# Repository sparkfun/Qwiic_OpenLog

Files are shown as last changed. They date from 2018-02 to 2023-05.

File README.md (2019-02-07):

SparkFun Qwiic OpenLog
========================================

SparkFun Qwiic OpenLog

[*SparkFun Qwiic OpenLog (DEV-15164)*](https://www.sparkfun.com/products/15164)

The [Qwiic](https://www.sparkfun.com/qwiic) system makes it easy to read all sorts of sensors, but what if you want to log that data? Qwiic OpenLog is an easy to use I2C based data logger. Simply write code like:

    recordToOpenLog("The battery voltage is:");
    recordToOpenLog(batteryVoltage);

And your data will be recorded to LOG00001.TXT for later review. 

The SparkFun Qwiic OpenLog is the smarter and better looking cousin to the extremely popular [OpenLog](https://www.sparkfun.com/products/13712). We've ported the serial based interface to I2C. Now you can daisy chain lots of I2C devices and log them all without taking up your serial port.

We've written a large number of example sketches to show how to record logs, create new logs, create and navigate directories, remove files and directories, and read the contents of files. 

Qwiic OpenLog supports clock stretching which means it performs even better than the original! Qwiic OpenLog will record data up to 21,000 bytes per second at 400kHz. As the receive buffer fills up QOL will hold the clock line letting the master know that it is busy. Once QOL is finished with a task it releases the clock allowing the data to continue flowing without corruption.

Need to get freaky and have multiple data loggers on the same bus? You're in luck. Qwiic OpenLog has both a solder jumper to allow for two devices on the same bus as well as a software setting to allow for the setting of any I2C address. Don't get too freaky though; the limit is 111 devices (0x08 to 0x77) on the same bus. Any microSD card will work so with 64GB cards you'll be limited to approximately 7 Terabytes of storage :(

We will be adding more features to the firmware over time and we've made it very easy to upgrade! If you're comfortable sending a sketch to an Uno then you can upgrade the firmware on Qwiic OpenLog.

Repository Contents
-------------------

* **/Firmware/Qwiic_OpenLog** - The core sketch that runs Qwiic OpenLog
* **/Hardware** - Eagle design files (.brd, .sch)

Documentation
--------------
* **[Library](https://github.com/sparkfun/SparkFun_Qwiic_OpenLog_Arduino_Library)** - Arduino library for the Qwiic OpenLog.
* **[Hookup Guide](https://learn.sparkfun.com/tutorials/qwiic-openlog-hookup-guide)** - Basic hookup guide for the Qwiic OpenLog.
* **[SparkFun Fritzing repo](https://github.com/sparkfun/Fritzing_Parts)** - Fritzing diagrams for SparkFun products.

License Information
-------------------

This product is _**open source**_! 

Please review the LICENSE.md file for license information. 

If you have any questions or concerns on licensing, please contact techsupport@sparkfun.com.

Please use, reuse, and modify these files as you see fit. Please maintain attribution to SparkFun Electronics and release any derivative under the same license.

Distributed as-is; no warranty is given.

- Your friends at SparkFun.

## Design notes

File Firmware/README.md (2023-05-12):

Library Dependencies:

* [SerialPort](https://github.com/greiman/SerialPort)
    * Users will need to manually install the [`SerialPort` folder](https://github.com/greiman/SerialPort/tree/master/SerialPort) from this repository as an Arduino library
        * Method 1:
            * Download or clone the repository
            * Compress the [`SerialPort` folder](https://github.com/greiman/SerialPort/tree/master/SerialPort) into a `*.zip` file
            * In the Arduino IDE, install the library from the drop-down menu: **Sketch** > **Include Library** > **Add .ZIP Library**
        * Method 2:
            * Download or clone the repository
            * Copy the [`SerialPort` folder](https://github.com/greiman/SerialPort/tree/master/SerialPort) into the directory for the Arduino libraries
* [SdFat *(v1.1.4)*](https://github.com/greiman/SdFat)
    * To avoid compile issues, please use v1.1.4 (or another version prior to v2.x.x) of the SDFat Arduino library

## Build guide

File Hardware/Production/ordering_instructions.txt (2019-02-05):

panel size, 195x122mm
PCB thickness, 1.6mm
number of layers, 2
soldermask color, Red
silkscreen color, White
oz copper, 1oz
finish, HASL lead free
stencils, top+bottom
pcs per panel, 28

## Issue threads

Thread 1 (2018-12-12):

Add Pullup on CS

nseidle, 2018-12-12:
Add ~10k pull up on SD CS so that the device can be programmed in test jig with SD card inserted. Otherwise the CS pin is left floating and can cause errors when the SD card tries to take over MISO during programming and testing.

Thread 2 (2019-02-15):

Example sketch won't compile, "default argument given for parameter 2"

mantonakakis1, 2019-02-15:
Example 1 sketch won't compile, I get the following error message(s):

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

If I remove the default argument from the sendCommand definition in the .cpp file, it compiles, i.e. when:
`boolean OpenLog::sendCommand(uint8_t registerNumber, String option1)`
replaces:
`boolean OpenLog::sendCommand(uint8_t registerNumber, String option1 = "")`

Using a SparkFun SAMD21 Pro RF and the SparkX qwiic OpenLog, I have another issue once the code is uploaded - the output of my .txt file on the SD card, running Example 1, looks like:
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

This matches an issue I had with another version of the library (as of Jan 26th, 2019) when used with the same hardware - randomly missing characters in the output file, skipped new lines, although no random up arrows (raised as an issue in the github for that version of the library, [here](https://github.com/sparkfun/SparkFun_Qwiic_OpenLog_Arduino_Library/issues/3)). Running the same sketch multiple times resulted in completely random point of error, i.e. sometimes a new line would come out correctly, other times it wouldn't, and would cut off in random spots. Now, with this version, I get the random up-arrows, as well as the randomly cut off lines.

Last I checked, the circa 1/26/2019 version of the library worked fine when the SparkX qwiic OpenLog was hooked up to a BlackBoard instead of the SAMD21 Pro RF.

AndyEngland521, 2019-02-15:
The SparkX version of the OpenLog runs a different firmware version than the new SparkFun OpenLog. You will need to update the firmware on your SparkX OpenLog to the most current version (contained in this repo) in order to get things working. In the mean time I'm looking into your compile error on SAMD21.

mattljc, 2019-02-24:
I'm having similar issues with the Red version of the qwiic OpenLog connected to a SAMD21 RedBoard Turbo. Running example 1 results in missing characters and missing newlines.

Things tried so far:
- Adding 100ms delays after print statements to ensure the buffers clear
- Increasing and decreasing the I2C clock speed
- Reducing string lengths to 8 chars

mantonakakis1, 2019-03-10:
> The SparkX version of the OpenLog runs a different firmware version than the new SparkFun OpenLog. You will need to update the firmware on your SparkX OpenLog to the most current version (contained in this repo) in order to get things working. In the mean time I'm looking into your compile error on SAMD21.

Updated the SparkX Qwiic OpenLog to firmware 2.0 by uploading the Qwiic_OpenLog.ino file from the latest firmware folder using an FTDI board (confirmed the firmware update worked by changing the "no card" error from 3 blinks to 2 blinks), making sure I followed the instructions in the HookUp guide regarding supprting libraries.

I then tried writing some simple data to the SD card with a BlackBoard. It writes consistently, but it is SLOW. With 20ms delay between three print commands (time, a comma, and a counter value), I get about 1.5 to 1.8 seconds per loop. It was also extremely slow running some of the examples in the library.

Tomorrow I will test with the non-X version of the OpenLog, without any firmware changes from the way it shipped, using the BlackBoard.

Here's the code I tested with:
```
#include <Wire.h>
#include "SparkFun_Qwiic_OpenLog_Arduino_Library.h"
OpenLog myLog;

int now = 0;
int loopDelay = 20;
int count = 0;

void setup()
{
  Serial.begin(9600);
  Serial.println("Starting");
  Wire.begin();
  Wire.setClock(400000);
  pinMode(LED_BUILTIN, OUTPUT);
  delay(100);
  myLog.begin();
  delay(100);
}

void loop()
{
  now = millis();
  myLog.print(now);
  delay(loopDelay);
  myLog.print(", ");
  delay(loopDelay);
  myLog.println(count);
  count++;
  digitalWrite(LED_BUILTIN, HIGH);
  delay(20);
  digitalWrite(LED_BUILTIN, LOW);
}
```

mantonakakis1, 2019-03-11:
After my last post I reflashed the firmware without any changes, and it suddenly worked a bit better - but for the 60ms of total delay in my loop function, I was getting about 150-250ms per loop. After a few seconds, one of the times through the loop would slow down a lot, closer to 1s, then back to ~200ms.

Tried the same sketch with the new "red" version of the Qwiic OpenLog with whatever firmware it shipped with, and got the same result.

Tried another SparkX version of the board, with whatever firmware it shipped with about 2 months ago, and it wrote much faster, subjectively looked like it was running at the full 60ms loop speed. Unfortunately, the new library doesn't match the firmware it and prints the garbled output with the "spades" symbols (so I can't say for sure how fast it was).

So I think I can conclude the following with a bit of confidence:
- New firmware is quite slow, regardless of board version, using the latest firmware and libraries on a BlackBoard.
- Old firmware doesn't work well with new libraries, which makes sense.
- New version of the board with stock firmware writes faster with a SAMD21 board, but incomplete print commands, missed new lines, etc.

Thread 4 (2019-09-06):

Can't flash OpenLog Qwiic

Stefal, 2019-09-06:
Hi!

My goal is to use OpenLog Qwiic as a standalone logger for the SparkFun GPS-RTK2 Board - ZED-F9P (Qwiic).

I've quick tested the OpenLog with an Arduino Uno and the OpenLog arduino library, and it's working.
My first step is simply updating the firmware with the latest one available here.
Then I will customize the code to log the F9P (any help is welcome).

But, I can't flash the OpenLog.

I've soldered the ftdi pins
Connected the OpenLog with an Adafruit Ftdi Friend/Sparkfun FTDI Basic 3.3v to a Windows Computer/Ubuntu Computer, and I always have the same problem :
```
avrdude: stk500_recv(): programmer is not responding
avrdude: stk500_getsync() attempt 1 of 10: not in sync: resp=0xde
```

I don't understand where is the problem.

nseidle, 2019-09-06:
Just to be sure - did you get the Qwiic OpenLog from us? It's happened a few times where derivatives from other mfgs neglect/forget the bootloader.

The board should have a regular Uno/Optiboot bootloader preloaded onto the board. Be sure nothing else is connected to the board except your FTDI. Sounds like your already at 3.3V on the FTDI (good). Try loading the basic blink sketch onto OpenLog. The Stat pin is pin 13 so the default BLINK sketch should work.

Stefal, 2019-09-06:
I bought it from [Digikey](https://www.digikey.fr/product-detail/en/sparkfun-electronics/DEV-15164/1568-DEV-15164-ND/9920435)

I can't flash the Blink sketch, I receive the same "not responding" error.

BTW : In all cases, when I start to upload the sketch, I see some activity on the FTDI adapter.

Thank you for your answer

Closed 2019-11-27.

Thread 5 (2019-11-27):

OpenLog Qwiic not working with STM32F429 Nucleo 144 Board

patilakash, 2019-11-27:
I am trying to log the data from STM32F429 board to Qwiic logger through I2C port. Below is settings for I2C in STM32F429
Address Mode: 10Bit
Clock Speed: 400K

Following commands are sent from STM32F429 board
1. Sent Data as "Testing"
2. Sent Register Address "13"
3. Sent Register Address "10"
4. Sent Register Address "17"

The I2C device ID used to communicate with Qwiic log is 42.

Please help me to solve the above issue. I have tested the Qwiic board with Arduino UNO and it is working.

AndyEngland521, 2019-11-27:
@patilakash hmmm, looks like the problem might be that you're using 10 bit addressing. If I remember correctly, the OpenLog and other Qwiic devices use an 8-bit addressing scheme. Check out the following [article](https://www.totalphase.com/support/articles/200349176-7-bit-8-bit-and-10-bit-I2C-Slave-Addressing)

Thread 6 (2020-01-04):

Characters dropped on Teensy 4.0

robertstuart, 2020-01-04:
When I compile and run the code below for a Teensy 4.0, many characters are dropped.  A typical output is also shown below.  The errors seem to be random. Adding delay(20) lines in the code seems to have no effect.  When I run the same code on an Arduino Mini Pro, the output is perfect.  I really, really would like to get this fixed.  Any ideas?

Just as a side note, I should mention that there is a compile error when compiling for a Teensy 3.2.  I don't need this but I thought someone should know.
```

#include <Wire.h>
#include "SparkFun_Qwiic_OpenLog_Arduino_Library.h"
OpenLog myLog; //Create instance

int ledPin = 13; //Status LED connected to digital pin 13
char message[100] = "";

void setup() {
  Serial.begin(115200);
  pinMode(ledPin, OUTPUT);
  Wire.begin(); //Initialize I2C
  myLog.begin(); //Open connection to OpenLog (no pun intended)
  for (float i = 0.0; i < 9.1; i += 0.5) {
    Serial.print(i); Serial.print(",");
    myLog.print(i); myLog.print(",");
    Serial.print(sqrt(i)); Serial.print(",");
    myLog.print(sqrt(i)); myLog.print(",");
    Serial.print(i / 0.99); Serial.print(",");
    myLog.print(i / 0.99); myLog.print(",");
    Serial.print(i * 1.1), Serial.print(",");
    myLog.print(i * 1.1), myLog.print(",");
    Serial.println(i);
    myLog.println(i);
  }
  myLog.syncFile();
}

void loop() {
  digitalWrite(ledPin, HIGH);
  delay(100);
  digitalWrite(ledPin, LOW);
  delay(1000);
}

```
```
0.00,0.00,0.00,0.00,0.00
0.50,0.710.51,0.55,0.50
1.00,1.00,1.01,1.10,1.00
1.50,1.22,1.52,1.65,1.50
2.00,1.41,2.02,2.20,2.00
2.50,1.58,2.53,2.75,2.50
3.00,1.73,3.03,3.30,3.00
3.50,1.87,3.5,3.85,3.50
4.00,2.00,4.04,4.40,4.00
4.50,2.12,4.55,4.95,4.50
5.00,2.24,5.05,5.50,5.00
5.0,2.35,5.56,6.05,5.50
6.00,2.45,6.06,6.60,6.00
6.50,2.55,6.57,7.15,6.50
7.00,2.65,7.07,7.0,7.00
7.50,2.74,7.58,8.25,7.50
8.00,2.83,8.08,8.80,8.00
8.50,2.92,8.59,9.35,8.50
9.00,3.00,9.09,9.90,9.0

```

Gambit120, 2021-03-31:
I am having the same issue on the teensy 4.0. I read some ware that there need to be a short delay between each character not between each write. I thought the library would have done this for you but it looks like you need to do it in your code.

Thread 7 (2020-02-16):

Errors in code

prem-prakash, 2020-02-16:
https://github.com/sparkfun/Qwiic_OpenLog/blob/4ad46f22de5928e600c73eadc97cb77bcad5d950/Firmware/Qwiic_OpenLog/Qwiic_OpenLog.ino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

this line should not be

```c++
  case ERROR_VOLUME_INIT:
      NewSerial.print(F("volume.init"));
      blink_error(ERROR_VOLUME_INIT);
      break;
```

otherwise, all errors blink the same number of times, a little bit confusing

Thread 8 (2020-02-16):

Compilation errors

prem-prakash, 2020-02-16:
Compile firmware code returning errors

```
Processing Qwiic_OpenLog (src_filter: +<Qwiic_OpenLog.cpp>; platform: atmelavr; framework: arduino; board: ATmega328; targets: program; monitor_speed: 115200; lib_deps: SdFat=https://github.com/greiman/SdFat-beta.git#7016042d22ec9e4a3fe93565bfff1d61fb8271e2)
-----------------------------------------------------------------------------------------------------------------------------------------------------------------------
CONFIGURATION: https://docs.platformio.org/page/boards/atmelavr/ATmega328.html
PLATFORM: Atmel AVR 2.0.0 > ATmega328
HARDWARE: ATMEGA328 16MHz, 2KB RAM, 31.50KB Flash
PACKAGES: toolchain-atmelavr 1.50400.190710 (5.4.0), framework-arduino-avr-minicore 2.0.3, tool-avrdude 1.60300.190628 (6.3.0)
LDF: Library Dependency Finder -> http://bit.ly/configure-pio-ldf
LDF Modes: Finder ~ chain, Compatibility ~ soft
Found 9 compatible libraries
Scanning dependencies...
Dependency Graph
|-- <SdFat> #7016042 [git+https://github.com/greiman/SdFat-beta.git#7016042d22ec9e4a3fe93565bfff1d61fb8271e2] (/Users/prakash/Projects/embedded/Qwiic_OpenLog/.pio/libdeps/Qwiic_OpenLog/SdFat)
|   |-- <SPI> 1.0 (/Users/prakash/.platformio/packages/framework-arduino-avr-minicore/libraries/SPI)
|-- <EEPROM> 2.0 (/Users/prakash/.platformio/packages/framework-arduino-avr-minicore/libraries/EEPROM)
|-- <SPI> 1.0 (/Users/prakash/.platformio/packages/framework-arduino-avr-minicore/libraries/SPI)
|-- <Wire> 1.0 (/Users/prakash/.platformio/packages/framework-arduino-avr-minicore/libraries/Wire)
Building in release mode
avr-g++ -o .pio/build/Qwiic_OpenLog/src/Qwiic_OpenLog.cpp.o -c -fno-exceptions -fno-threadsafe-statics -fpermissive -std=gnu++11 -Os -Wall -ffunction-sections -fdata-sections -flto -mmcu=atmega328 -DPLATFORMIO=40100 -DARDUINO_AVR_ATmega328 -DF_CPU=16000000L -DARDUINO_ARCH_AVR -DARDUINO=10808 -Iinclude -Isrc -I/Users/prakash/.platformio/packages/framework-arduino-avr-minicore/libraries/Wire/src -I/Users/prakash/.platformio/packages/framework-arduino-avr-minicore/libraries/EEPROM/src -I.pio/libdeps/Qwiic_OpenLog/SdFat -I/Users/prakash/.platformio/packages/framework-arduino-avr-minicore/libraries/SPI/src -I/Users/prakash/.platformio/packages/framework-arduino-avr-minicore/cores/MiniCore -I/Users/prakash/.platformio/packages/framework-arduino-avr-minicore/variants/standard src/Qwiic_OpenLog.cpp
In file included from .pio/libdeps/Qwiic_OpenLog/SdFat/SdFat/src/FatLib/FatLib.h:28:0,
                 from .pio/libdeps/Qwiic_OpenLog/SdFat/SdFat/src/SdFat.h:27,
                 from src/Qwiic_OpenLog.cpp:93:
.pio/libdeps/Qwiic_OpenLog/SdFat/SdFat/src/FatLib/StdioStream.h:289:24: warning: 'prog_char' is deprecated [-Wdeprecated-declarations]
   int fputs_P(PGM_P str);
                        ^
In file included from src/Qwiic_OpenLog.cpp:94:0:
include/SerialPort.h:243:41: warning: 'prog_char' is deprecated [-Wdeprecated-declarations]
   buf_size_t put_P(PGM_P b, buf_size_t n);
                                         ^
include/SerialPort.h:547:35: warning: 'prog_char' is deprecated [-Wdeprecated-declarations]
   size_t write_P(PGM_P b, size_t n) {
                                   ^
include/SerialPort.h: In member function 'size_t SerialPort<PortNumber, RxBufSize, TxBufSize>::write(const __FlashStringHelper*)':
include/SerialPort.h:583:22: warning: 'prog_char' is deprecated: prog_char type is deprecated. [-Wdeprecated-declarations]
     const prog_char* p = (const prog_char*)s;
                      ^
In file included from /Users/prakash/.platformio/packages/framework-arduino-avr-minicore/cores/MiniCore/Arduino.h:28:0,
                 from /Users/prakash/.platformio/packages/framework-arduino-avr-minicore/libraries/Wire/src/Wire.h:25,
                 from src/Qwiic_OpenLog.cpp:91:
/Users/prakash/.platformio/packages/toolchain-atmelavr/avr/include/avr/pgmspace.h:354:14: note: declared here
 typedef char prog_char __attribute__((__progmem__,deprecated("prog_char type is deprecated.")));
              ^
In file included from src/Qwiic_OpenLog.cpp:94:0:
include/SerialPort.h:583:42: warning: 'prog_char' is deprecated: prog_char type is deprecated. [-Wdeprecated-declarations]
     const prog_char* p = (const prog_char*)s;
                                          ^
In file included from /Users/prakash/.platformio/packages/framework-arduino-avr-minicore/cores/MiniCore/Arduino.h:28:0,
                 from /Users/prakash/.platformio/packages/framework-arduino-avr-minicore/libraries/Wire/src/Wire.h:25,
                 from src/Qwiic_OpenLog.cpp:91:
/Users/prakash/.platformio/packages/toolchain-atmelavr/avr/include/avr/pgmspace.h:354:14: note: declared here
 typedef char prog_char __attribute__((__progmem__,deprecated("prog_char type is deprecated.")));
              ^
src/Qwiic_OpenLog.cpp: In function 'void recordConfigFile()':
src/Qwiic_OpenLog.cpp:603:62: warning: comparison between signed and unsigned integer expressions [-Wsign-compare]
   if (myFile.write(settings_string, strlen(settings_string)) != strlen(settings_string))
                                                              ^
src/Qwiic_OpenLog.cpp: In function 'void loadArrayWithFileName(FatFile*, char*)':
src/Qwiic_OpenLog.cpp:1183:53: warning: invalid conversion from 'byte* {aka unsigned char*}' to 'char*' [-fpermissive]
   responseSize = sprintf(responseBuffer, "%s", fname) + 1; //Add 1 for null terminator
                                                     ^
In file included from /Users/prakash/.platformio/packages/framework-arduino-avr-minicore/cores/MiniCore/Print.h:24:0,
                 from /Users/prakash/.platformio/packages/framework-arduino-avr-minicore/cores/MiniCore/Stream.h:26,
                 from /Users/prakash/.platformio/packages/framework-arduino-avr-minicore/cores/MiniCore/HardwareSerial.h:29,
                 from /Users/prakash/.platformio/packages/framework-arduino-avr-minicore/cores/MiniCore/Arduino.h:288,
                 from /Users/prakash/.platformio/packages/framework-arduino-avr-minicore/libraries/Wire/src/Wire.h:25,
                 from src/Qwiic_OpenLog.cpp:91:
/Users/prakash/.platformio/packages/toolchain-atmelavr/avr/include/stdio.h:671:12: note:   initializing argument 1 of 'int sprintf(char*, const char*, ...)'
 extern int sprintf(char *__s, const char *__fmt, ...);
            ^
src/Qwiic_OpenLog.cpp: In function 'void listFiles(char*)':
src/Qwiic_OpenLog.cpp:1206:12: warning: ISO C++ forbids converting a string constant to 'char*' [-Wwrite-strings]
     myData = "*\0";       // use global wildcard=
            ^
src/Qwiic_OpenLog.cpp: In function 'void receiveEvent(int)':
src/Qwiic_OpenLog.cpp:1363:31: warning: comparison between signed and unsigned integer expressions [-Wsign-compare]
   for (int regNum = 0; regNum < (sizeof(memoryMap) / sizeof(byte)); regNum++)
                               ^
src/Qwiic_OpenLog.cpp:1369:52: warning: invalid conversion from 'byte* {aka unsigned char*}' to 'char*' [-fpermissive]
       functions[regNum].handleFunction(incomingData);
                                                    ^
In file included from src/Qwiic_OpenLog.cpp:96:0:
src/Qwiic_OpenLog.cpp: At top level:
.pio/libdeps/Qwiic_OpenLog/SdFat/SdFat/src/FreeStack.h:40:12: warning: 'FreeStack' defined but not used [-Wunused-function]
 static int FreeStack() {
            ^
avr-g++ -o .pio/build/Qwiic_OpenLog/firmware.elf -Os -mmcu=atmega328 -Wl,--gc-sections -flto -fuse-linker-plugin .pio/build/Qwiic_OpenLog/src/Qwiic_OpenLog.cpp.o -L.pio/build/Qwiic_OpenLog -Wl,--start-group .pio/build/Qwiic_OpenLog/lib10a/libSPI.a .pio/build/Qwiic_OpenLog/lib201/libSdFat.a .pio/build/Qwiic_OpenLog/lib356/libEEPROM.a .pio/build/Qwiic_OpenLog/libff3/libWire.a .pio/build/Qwiic_OpenLog/libFrameworkArduinoVariant.a .pio/build/Qwiic_OpenLog/libFrameworkArduino.a -lm -Wl,--end-group
/var/folders/f2/ps6dm9rs3y7dqg7xr8_k9_2h0000gn/T//ccy0Fwvq.ltrans0.ltrans.o: In function `SerialPort<(unsigned char)0, 32u, 32u>::flush()':
<artificial>:(.text+0x6c6): undefined reference to `txRingBuf'
<artificial>:(.text+0x6ca): undefined reference to `txRingBuf'
<artificial>:(.text+0x6ce): undefined reference to `txRingBuf'
<artificial>:(.text+0x6d2): undefined reference to `txRingBuf'
/var/folders/f2/ps6dm9rs3y7dqg7xr8_k9_2h0000gn/T//ccy0Fwvq.ltrans0.ltrans.o: In function `SerialPort<(unsigned char)0, 32u, 32u>::peek()':
<artificial>:(.text+0xe1c): undefined reference to `rxRingBuf'
<artificial>:(.text+0xe1e): undefined reference to `rxRingBuf'
<artificial>:(.text+0xe20): undefined reference to `SerialRingBuffer::peek()'
/var/folders/f2/ps6dm9rs3y7dqg7xr8_k9_2h0000gn/T//ccy0Fwvq.ltrans0.ltrans.o: In function `SerialPort<(unsigned char)0, 32u, 32u>::read()':
<artificial>:(.text+0xe34): undefined reference to `rxRingBuf'
<artificial>:(.text+0xe36): undefined reference to `rxRingBuf'
<artificial>:(.text+0xe38): undefined reference to `SerialRingBuffer::get(unsigned char*)'
/var/folders/f2/ps6dm9rs3y7dqg7xr8_k9_2h0000gn/T//ccy0Fwvq.ltrans0.ltrans.o: In function `SerialPort<(unsigned char)0, 32u, 32u>::available()':
<artificial>:(.text+0xe52): undefined reference to `rxRingBuf'
<artificial>:(.text+0xe54): undefined reference to `rxRingBuf'
<artificial>:(.text+0xe56): undefined reference to `SerialRingBuffer::available()'
/var/folders/f2/ps6dm9rs3y7dqg7xr8_k9_2h0000gn/T//ccy0Fwvq.ltrans0.ltrans.o: In function `SerialPort<(unsigned char)0, 32u, 32u>::write(unsigned char const*, unsigned int)':
<artificial>:(.text+0xe76): undefined reference to `txRingBuf'
<artificial>:(.text+0xe78): undefined reference to `txRingBuf'
<artificial>:(.text+0xe7a): undefined reference to `SerialRingBuffer::put(unsigned char const*, unsigned int)'
/var/folders/f2/ps6dm9rs3y7dqg7xr8_k9_2h0000gn/T//ccy0Fwvq.ltrans0.ltrans.o: In function `SerialPort<(unsigned char)0, 32u, 32u>::write(unsigned char)':
<artificial>:(.text+0xeaa): undefined reference to `txRingBuf'
<artificial>:(.text+0xeac): undefined reference to `txRingBuf'
<artificial>:(.text+0xeae): undefined reference to `SerialRingBuffer::put(unsigned char)'
/var/folders/f2/ps6dm9rs3y7dqg7xr8_k9_2h0000gn/T//ccy0Fwvq.ltrans0.ltrans.o: In function `global constructors keyed to 65535_0_Qwiic_OpenLog.cpp.o.3638':
<artificial>:(.text.startup+0x40): undefined reference to `rxRingBuf'
<artificial>:(.text.startup+0x42): undefined reference to `rxRingBuf'
<artificial>:(.text.startup+0x44): undefined reference to `SerialRingBuffer::init(unsigned char*, unsigned int)'
<artificial>:(.text.startup+0x50): undefined reference to `txRingBuf'
<artificial>:(.text.startup+0x52): undefined reference to `txRingBuf'
<artificial>:(.text.startup+0x54): undefined reference to `SerialRingBuffer::init(unsigned char*, unsigned int)'
/var/folders/f2/ps6dm9rs3y7dqg7xr8_k9_2h0000gn/T//ccy0Fwvq.ltrans0.ltrans.o: In function `main':
<artificial>:(.text.startup+0xea): undefined reference to `fopen'
<artificial>:(.text.startup+0x170): undefined reference to `fopen'
collect2: error: ld returned 1 exit status
```

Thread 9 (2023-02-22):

Problem on interfacing Qwiic OpenLog throught NUCLEO STM32 L432KC

DamianTadzik, 2023-02-22:
I'm trying to write my own library for my own use, based on Arduino library and information that SparkFun provided about this logger but i'm always recievieng HAL_error. I do not know where to find help or information about configuring this device, and it feels like register map is useless because any of those addresses doesn't respond.

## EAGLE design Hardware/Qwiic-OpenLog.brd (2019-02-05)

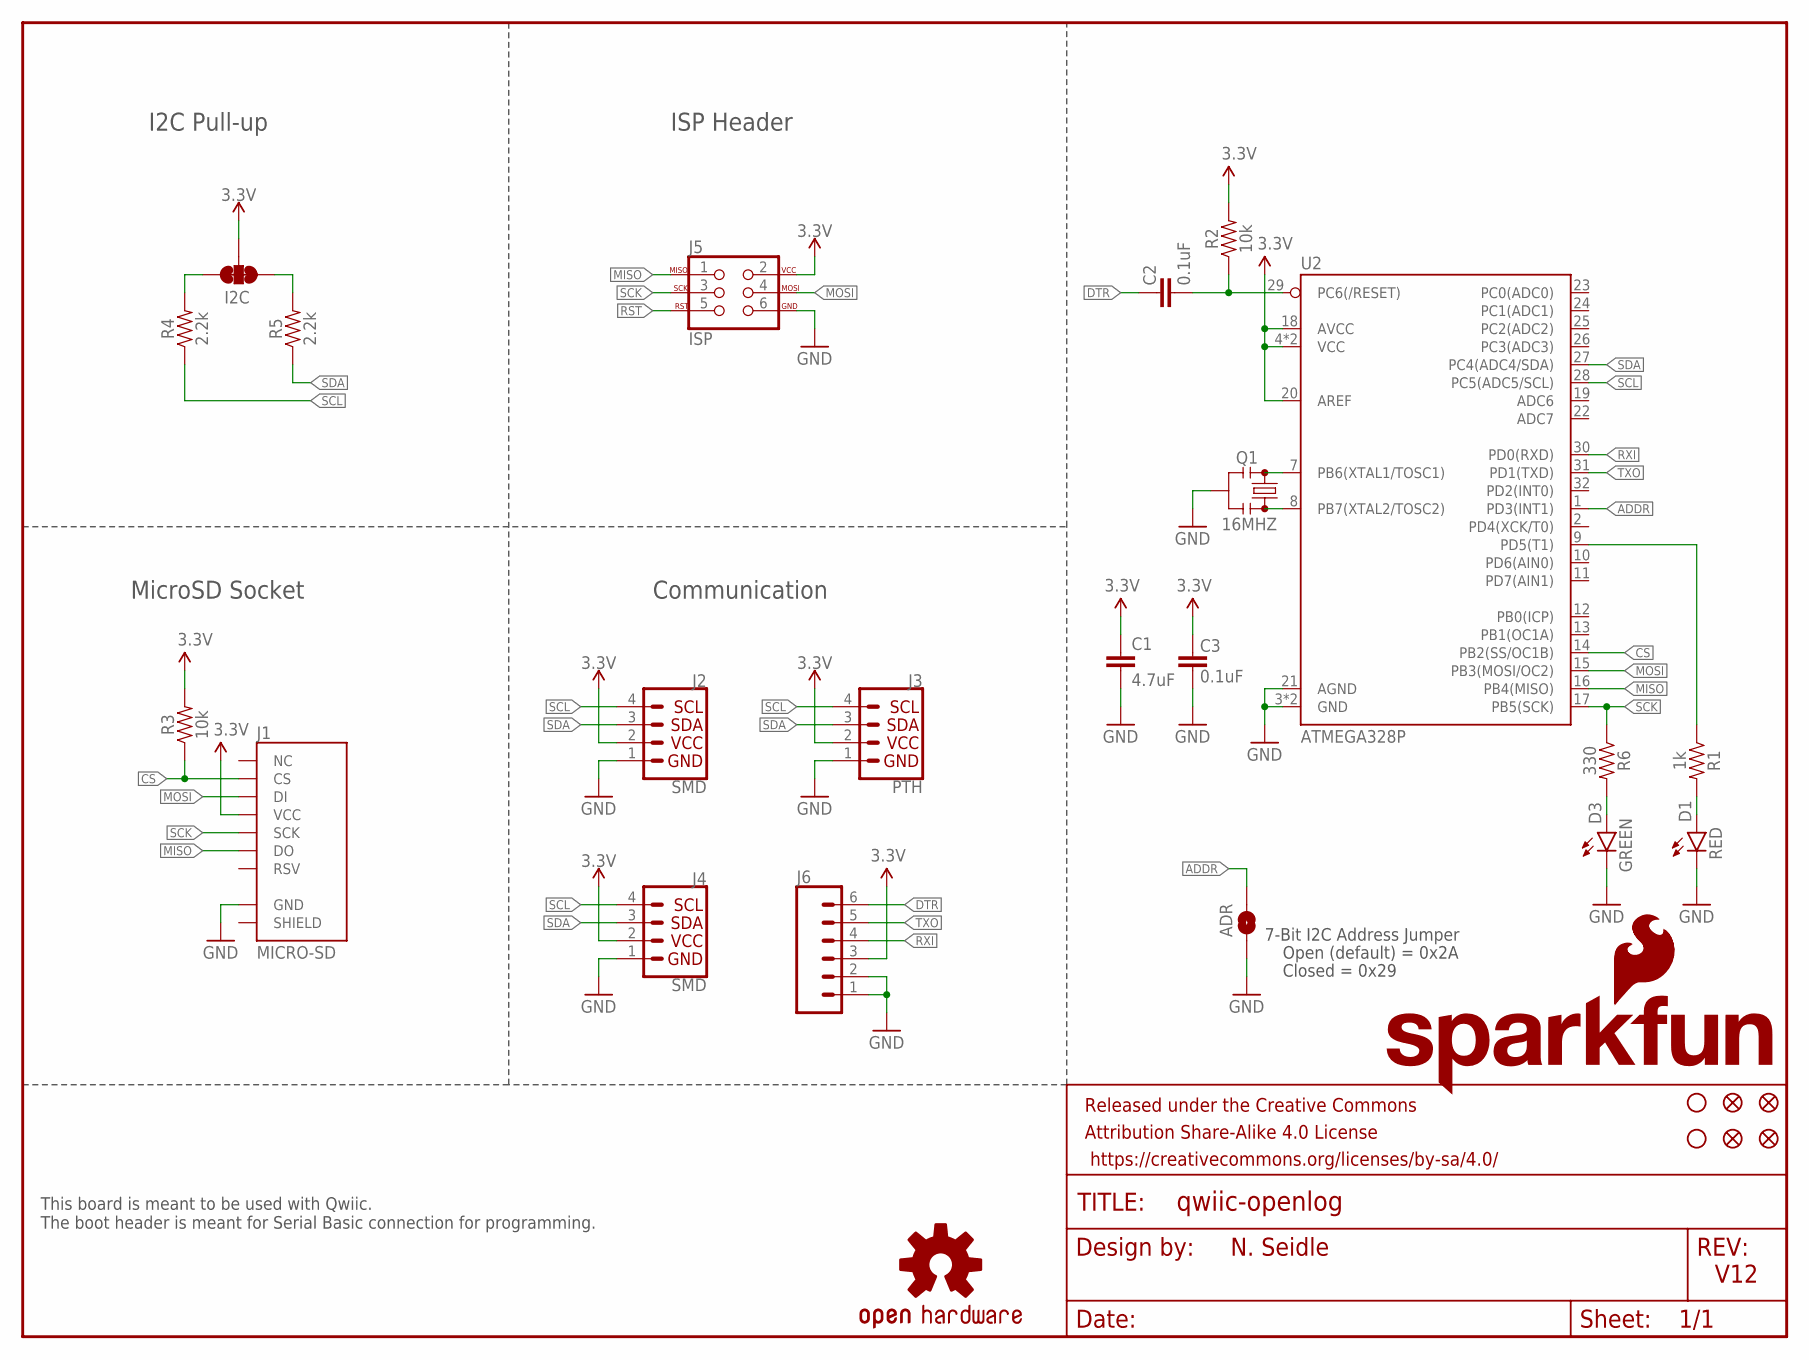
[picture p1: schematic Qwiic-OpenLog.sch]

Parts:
ADR: SOLDERJUMPERNO; SJ_2S-NO
C1: 4.7uF; 0603
C2, C3: 0.1uF; 0603
D1: RED; LED-0603
D3: GREEN; LED-0603
FID1, FID2, FID3, FID4: FIDUCIALUFIDUCIAL; FIDUCIAL-MICRO
FRAME1: FRAME-LETTER; CREATIVE_COMMONS
I2C: JUMPER-SMT_3_2-NC_TRACE_SILK; SMT-JUMPER_3_2-NC_TRACE_SILK
J1: MICRO-SD; MICRO-SD-SOCKET
J2, J4: SMD; 1X04_1MM_RA
J3: PTH; 1X04_NO_SILK
J5: ISP; 2X3_TEST_POINTS
J6: CONN_06NO_SILK_NO_POP; 1X06_NO_SILK
JP3, JP4: STAND-OFF
LOGO1: SFE_LOGO_FLAME.1_INCH; SFE_LOGO_FLAME_.1
LOGO2: OSHW-LOGOMINI; OSHW-LOGO-MINI
LOGO4: SFE_LOGO_NAME_FLAME.1_INCH; SFE_LOGO_NAME_FLAME_.1
Q1: 16MHZ; RESONATOR-SMD
R1: 1k; 0603
R2, R3: 10k; 0603
R4, R5: 2.2k; 0603
R6: 330; 0603
U2: ATMEGA328P; TQFP32-08

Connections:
3.3V: C1.1, C3.2, I2C.2, J1.VCC, J2.2, J3.2 (VCC), J4.2, J5.2, J6.3, R2.2, R3.2, U2.4 (VCC), U2.6 (VCC), U2.18 (AVCC), U2.20 (AREF)
ADDR: ADR.2, U2.1 (PD3(INT1))
CS: J1.CS, R3.1, U2.14 (PB2(SS/OC1B))
DTR: C2.2, J6.6
GND: ADR.1, C1.2, C3.1, D1.C, D3.C, J1.GND, J2.1, J3.1 (GND), J4.1, J5.6, J6.1, J6.2, Q1.2, U2.3 (GND), U2.5 (GND), U2.21 (AGND)
MISO: J1.DO, J5.1, U2.16 (PB4(MISO))
MOSI: J1.DI, J5.4, U2.15 (PB3(MOSI/OC2))
unnamed: Q1.1, U2.8 (PB7(XTAL2/TOSC2))
unnamed: Q1.3, U2.7 (PB6(XTAL1/TOSC1))
unnamed: D1.A, R1.2
unnamed: R1.1, U2.9 (PD5(T1))
unnamed: I2C.1, R5.2
unnamed: I2C.3, R4.2
unnamed: D3.A, R6.2
RST: C2.1, J5.5, R2.1, U2.29 (PC6(/RESET))
RXI: J6.4, U2.30 (PD0(RXD))
SCK: J1.SCLK (SCK), J5.3, R6.1, U2.17 (PB5(SCK))
SCL: J2.4, J3.4 (SCL), J4.4, R4.1, U2.28 (PC5(ADC5/SCL))
SDA: J2.3, J3.3 (SDA), J4.3, R5.1, U2.27 (PC4(ADC4/SDA))
TXO: J6.5, U2.31 (PD1(TXD))

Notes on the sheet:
This board is meant to be used with Qwiic. The boot header is meant for Serial Basic connection for programming.
V12
N. Seidle
I2C Pull-up
Communication
MicroSD Socket
ISP Header
7-Bit I2C Address Jumper
Closed = 0x29
Open (default) = 0x2A

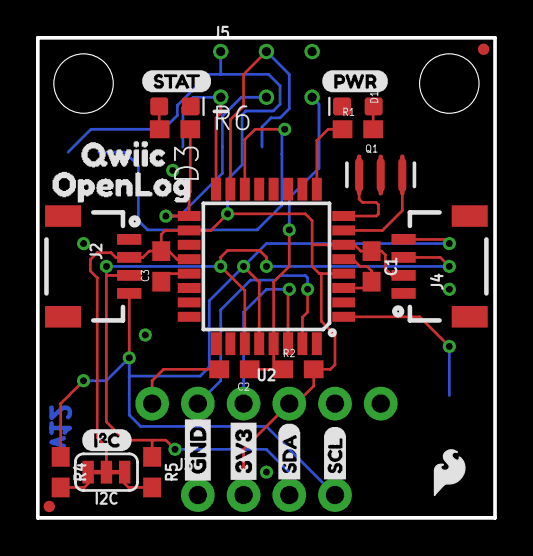
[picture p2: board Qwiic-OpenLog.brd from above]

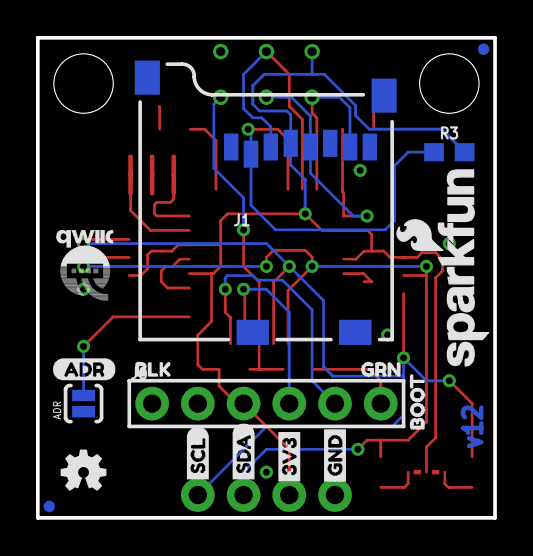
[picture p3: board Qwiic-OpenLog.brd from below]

Board: 2 copper layers, 25.4 x 26.7 mm, 49 parts (17 on the bottom side), 20 nets.

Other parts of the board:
U$3: QWIIC-LOGO-SMALL
U$4: 3V3-03
U$5: GND-03
U$6: 3V30
U$7: ADR-()-03
U$8: I_SUPER2_C-()-03
U$9: PWR-()-03
U$10: BLK3
U$11: BOOT5
U$12: GRN4
U$13, U$16: SDA1
U$14: QWIIC7
U$15, U$19: SCL2
U$17: STAT0
U$18: OPENLOG0
U$20: GND1

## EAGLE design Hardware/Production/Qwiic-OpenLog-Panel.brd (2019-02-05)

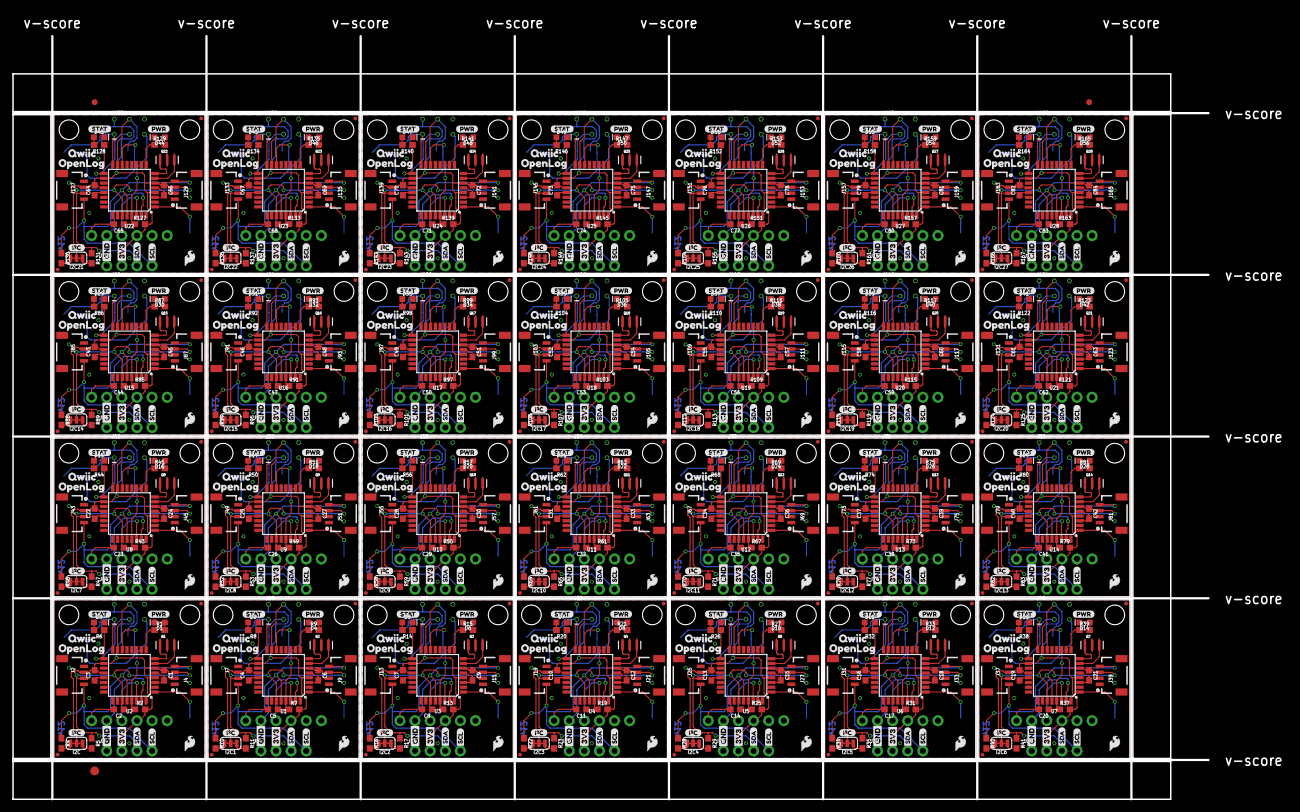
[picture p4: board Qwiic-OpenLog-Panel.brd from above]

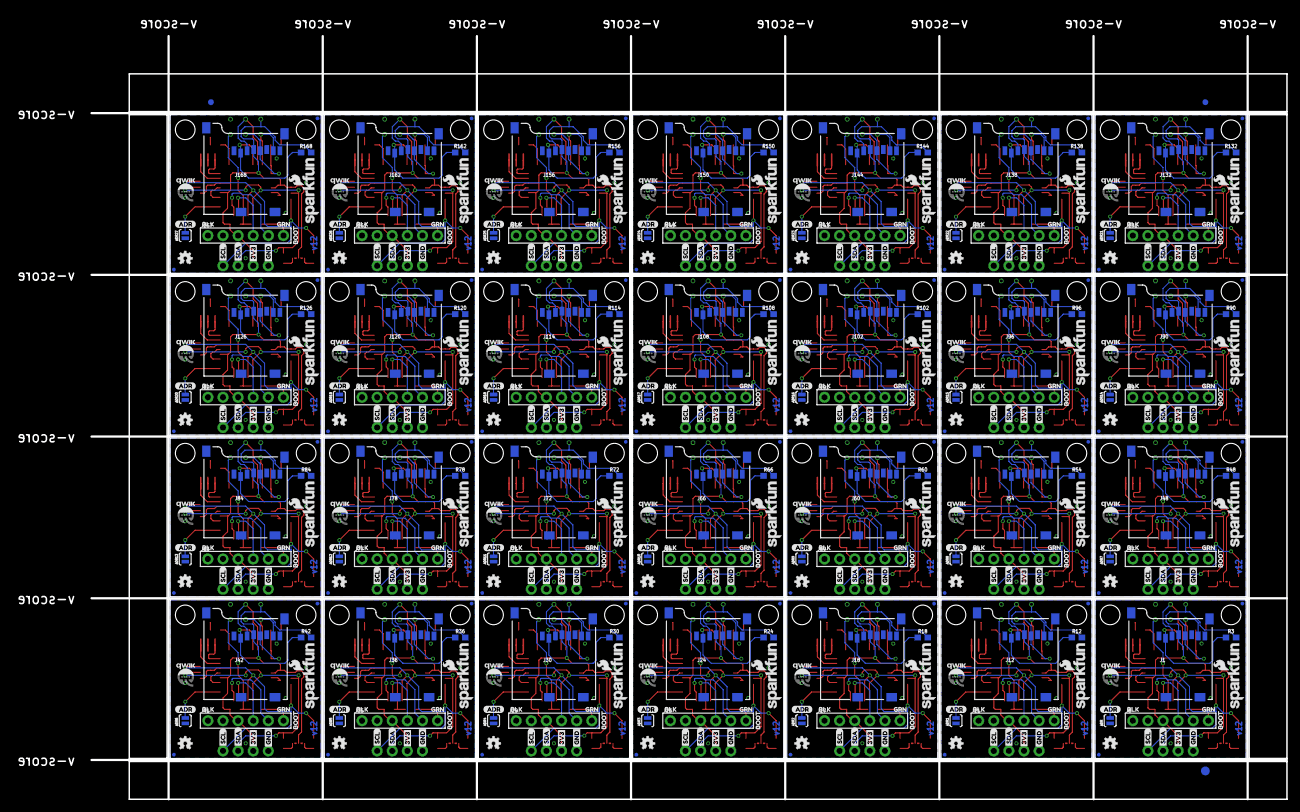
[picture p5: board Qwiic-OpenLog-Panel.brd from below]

Board: 2 copper layers, 200.9 x 128.3 mm, 1350 parts (479 on the bottom side), 560 nets.

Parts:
ADR, ADR1, ADR2, ADR3, ADR4, ADR5, ADR6, ADR7, ADR8, ADR9, ADR10, ADR11, ADR12, ADR13, ADR14, ADR15, ADR16, ADR17, ADR18, ADR19, ADR20, ADR21, ADR22, ADR23, ADR24, ADR25, ADR26, ADR27: SJ_2S-NO
C1, C6, C9, C12, C15, C18, C21, C24, C27, C30, C33, C36, C39, C42, C45, C48, C51, C54, C57, C60, C63, C66, C69, C72, C75, C78, C81, C84: 4.7uF; 0603
C2, C3, C4, C5, C7, C8, C10, C11, C13, C14, C16, C17, C19, C20, C22, C23, C25, C26, C28, C29, C31, C32, C34, C35, C37, C38, C40, C41, C43, C44, C46, C47, C49, C50, C52, C53, C55, C56, C58, C59, C61, C62, C64, C65, C67, C68, C70, C71, C73, C74, C76, C77, C79, C80, C82, C83: 0.1uF; 0603
D1, D4, D6, D8, D10, D12, D14, D16, D18, D20, D22, D24, D26, D28, D30, D32, D34, D36, D38, D40, D42, D44, D46, D48, D50, D52, D54, D56: RED; LED-0603
D2, D3, D5, D7, D9, D11, D13, D15, D17, D19, D21, D23, D25, D27, D29, D31, D33, D35, D37, D39, D41, D43, D45, D47, D49, D51, D53, D55: GREEN; LED-0603
E$1, E$2, E$3, E$4: FIDUCIAL-1X2
E$5, E$6: FIDUCIAL-1.5X3
FID1, FID2, FID3, FID4, FID5, FID6, FID7, FID8, FID9, FID10, FID11, FID12, FID13, FID14, FID15, FID16, FID17, FID18, FID19, FID20, FID21, FID22, FID23, FID24, FID25, FID26, FID27, FID28, FID29, FID30, FID31, FID32, FID33, FID34, FID35, FID36, FID37, FID38, FID39, FID40, FID41, FID42, FID43, FID44, FID45, FID46, FID47, FID48, FID49, FID50, FID51, FID52, FID53, FID54, FID55, FID56, FID57, FID58, FID59, FID60, FID61, FID62, FID63, FID64, FID65, FID66, FID67, FID68, FID69, FID70, FID71, FID72, FID73, FID74, FID75, FID76, FID77, FID78, FID79, FID80, FID81, FID82, FID83, FID84, FID85, FID86, FID87, FID88, FID89, FID90, FID91, FID92, FID93, FID94, FID95, FID96, FID97, FID98, FID99, FID100, FID101, FID102, FID103, FID104, FID105, FID106, FID107, FID108, FID109, FID110, FID111, FID112: FIDUCIALUFIDUCIAL; FIDUCIAL-MICRO
I2C, I2C1, I2C2, I2C3, I2C4, I2C5, I2C6, I2C7, I2C8, I2C9, I2C10, I2C11, I2C12, I2C13, I2C14, I2C15, I2C16, I2C17, I2C18, I2C19, I2C20, I2C21, I2C22, I2C23, I2C24, I2C25, I2C26, I2C27: SMT-JUMPER_3_2-NC_TRACE_SILK
J1, J12, J18, J24, J30, J36, J42, J48, J54, J60, J66, J72, J78, J84, J90, J96, J102, J108, J114, J120, J126, J132, J138, J144, J150, J156, J162, J168: MICRO-SD; MICRO-SD-SOCKET
J2, J4, J7, J9, J13, J15, J19, J21, J25, J27, J31, J33, J37, J39, J43, J45, J49, J51, J55, J57, J61, J63, J67, J69, J73, J75, J79, J81, J85, J87, J91, J93, J97, J99, J103, J105, J109, J111, J115, J117, J121, J123, J127, J129, J133, J135, J139, J141, J145, J147, J151, J153, J157, J159, J163, J165: SMD; 1X04_1MM_RA
J3, J8, J14, J20, J26, J32, J38, J44, J50, J56, J62, J68, J74, J80, J86, J92, J98, J104, J110, J116, J122, J128, J134, J140, J146, J152, J158, J164: PTH; 1X04_NO_SILK
J5, J10, J16, J22, J28, J34, J40, J46, J52, J58, J64, J70, J76, J82, J88, J94, J100, J106, J112, J118, J124, J130, J136, J142, J148, J154, J160, J166: ISP; 2X3_TEST_POINTS
J6, J11, J17, J23, J29, J35, J41, J47, J53, J59, J65, J71, J77, J83, J89, J95, J101, J107, J113, J119, J125, J131, J137, J143, J149, J155, J161, J167: 1X06_NO_SILK
JP1, JP2, JP3, JP4, JP5, JP6, JP7, JP8, JP9, JP10, JP11, JP12, JP13, JP14, JP15, JP16, JP17, JP18, JP19, JP20, JP21, JP22, JP23, JP24, JP25, JP26, JP27, JP28, JP29, JP30, JP31, JP32, JP33, JP34, JP35, JP36, JP37, JP38, JP39, JP40, JP41, JP42, JP43, JP44, JP45, JP46, JP47, JP48, JP49, JP50, JP51, JP52, JP53, JP54, JP55, JP56: STAND-OFF
LOGO1, LOGO6, LOGO9, LOGO12, LOGO15, LOGO18, LOGO21, LOGO24, LOGO27, LOGO30, LOGO33, LOGO36, LOGO39, LOGO42, LOGO45, LOGO48, LOGO51, LOGO54, LOGO57, LOGO60, LOGO63, LOGO66, LOGO69, LOGO72, LOGO75, LOGO78, LOGO81, LOGO84: SFE_LOGO_FLAME.1_INCH; SFE_LOGO_FLAME_.1
LOGO2, LOGO3, LOGO7, LOGO10, LOGO13, LOGO16, LOGO19, LOGO22, LOGO25, LOGO28, LOGO31, LOGO34, LOGO37, LOGO40, LOGO43, LOGO46, LOGO49, LOGO52, LOGO55, LOGO58, LOGO61, LOGO64, LOGO67, LOGO70, LOGO73, LOGO76, LOGO79, LOGO82: OSHW-LOGOMINI; OSHW-LOGO-MINI
LOGO4, LOGO5, LOGO8, LOGO11, LOGO14, LOGO17, LOGO20, LOGO23, LOGO26, LOGO29, LOGO32, LOGO35, LOGO38, LOGO41, LOGO44, LOGO47, LOGO50, LOGO53, LOGO56, LOGO59, LOGO62, LOGO65, LOGO68, LOGO71, LOGO74, LOGO77, LOGO80, LOGO83: SFE_LOGO_NAME_FLAME.1_INCH; SFE_LOGO_NAME_FLAME_.1
Q1, Q2, Q3, Q4, Q5, Q6, Q7, Q8, Q9, Q10, Q11, Q12, Q13, Q14, Q15, Q16, Q17, Q18, Q19, Q20, Q21, Q22, Q23, Q24, Q25, Q26, Q27, Q28: 16MHZ; RESONATOR-SMD
R1, R9, R15, R21, R27, R33, R39, R45, R51, R57, R63, R69, R75, R81, R87, R93, R99, R105, R111, R117, R123, R129, R135, R141, R147, R153, R159, R165: 1k; 0603
R2, R3, R7, R12, R13, R18, R19, R24, R25, R30, R31, R36, R37, R42, R43, R48, R49, R54, R55, R60, R61, R66, R67, R72, R73, R78, R79, R84, R85, R90, R91, R96, R97, R102, R103, R108, R109, R114, R115, R120, R121, R126, R127, R132, R133, R138, R139, R144, R145, R150, R151, R156, R157, R162, R163, R168: 10k; 0603
R4, R5, R10, R11, R16, R17, R22, R23, R28, R29, R34, R35, R40, R41, R46, R47, R52, R53, R58, R59, R64, R65, R70, R71, R76, R77, R82, R83, R88, R89, R94, R95, R100, R101, R106, R107, R112, R113, R118, R119, R124, R125, R130, R131, R136, R137, R142, R143, R148, R149, R154, R155, R160, R161, R166, R167: 2.2k; 0603
R6, R8, R14, R20, R26, R32, R38, R44, R50, R56, R62, R68, R74, R80, R86, R92, R98, R104, R110, R116, R122, R128, R134, R140, R146, R152, R158, R164: 330; 0603
U1, U2, U3, U4, U5, U6, U7, U8, U9, U10, U11, U12, U13, U14, U15, U16, U17, U18, U19, U20, U21, U22, U23, U24, U25, U26, U27, U28: ATMEGA328P; TQFP32-08
U$1, U$4, U$37, U$55, U$73, U$91, U$109, U$127, U$145, U$163, U$181, U$199, U$217, U$235, U$253, U$271, U$289, U$307, U$325, U$343, U$361, U$379, U$397, U$415, U$433, U$451, U$469, U$487: 3V3-03
U$2, U$5, U$38, U$56, U$74, U$92, U$110, U$128, U$146, U$164, U$182, U$200, U$218, U$236, U$254, U$272, U$290, U$308, U$326, U$344, U$362, U$380, U$398, U$416, U$434, U$452, U$470, U$488: GND-03
U$3, U$36, U$54, U$72, U$90, U$108, U$126, U$144, U$162, U$180, U$198, U$216, U$234, U$252, U$270, U$288, U$306, U$324, U$342, U$360, U$378, U$396, U$414, U$432, U$450, U$468, U$486, U$504: QWIIC-LOGO-SMALL
U$6, U$34, U$52, U$70, U$88, U$106, U$124, U$142, U$160, U$178, U$196, U$214, U$232, U$250, U$268, U$286, U$304, U$322, U$340, U$358, U$376, U$394, U$412, U$430, U$448, U$466, U$484, U$502: 3V30
U$7, U$21, U$39, U$57, U$75, U$93, U$111, U$129, U$147, U$165, U$183, U$201, U$219, U$237, U$255, U$273, U$291, U$309, U$327, U$345, U$363, U$381, U$399, U$417, U$435, U$453, U$471, U$489: ADR-()-03
U$8, U$22, U$40, U$58, U$76, U$94, U$112, U$130, U$148, U$166, U$184, U$202, U$220, U$238, U$256, U$274, U$292, U$310, U$328, U$346, U$364, U$382, U$400, U$418, U$436, U$454, U$472, U$490: I_SUPER2_C-()-03
U$9, U$23, U$41, U$59, U$77, U$95, U$113, U$131, U$149, U$167, U$185, U$203, U$221, U$239, U$257, U$275, U$293, U$311, U$329, U$347, U$365, U$383, U$401, U$419, U$437, U$455, U$473, U$491: PWR-()-03
U$10, U$24, U$42, U$60, U$78, U$96, U$114, U$132, U$150, U$168, U$186, U$204, U$222, U$240, U$258, U$276, U$294, U$312, U$330, U$348, U$366, U$384, U$402, U$420, U$438, U$456, U$474, U$492: BLK3
U$11, U$25, U$43, U$61, U$79, U$97, U$115, U$133, U$151, U$169, U$187, U$205, U$223, U$241, U$259, U$277, U$295, U$313, U$331, U$349, U$367, U$385, U$403, U$421, U$439, U$457, U$475, U$493: BOOT5
U$12, U$26, U$44, U$62, U$80, U$98, U$116, U$134, U$152, U$170, U$188, U$206, U$224, U$242, U$260, U$278, U$296, U$314, U$332, U$350, U$368, U$386, U$404, U$422, U$440, U$458, U$476, U$494: GRN4
U$13, U$16, U$29, U$32, U$47, U$50, U$65, U$68, U$83, U$86, U$101, U$104, U$119, U$122, U$137, U$140, U$155, U$158, U$173, U$176, U$191, U$194, U$209, U$212, U$227, U$230, U$245, U$248, U$263, U$266, U$281, U$284, U$299, U$302, U$317, U$320, U$335, U$338, U$353, U$356, U$371, U$374, U$389, U$392, U$407, U$410, U$425, U$428, U$443, U$446, U$461, U$464, U$479, U$482, U$497, U$500: SDA1
U$14, U$27, U$45, U$63, U$81, U$99, U$117, U$135, U$153, U$171, U$189, U$207, U$225, U$243, U$261, U$279, U$297, U$315, U$333, U$351, U$369, U$387, U$405, U$423, U$441, U$459, U$477, U$495: QWIIC7
U$15, U$19, U$28, U$33, U$46, U$51, U$64, U$69, U$82, U$87, U$100, U$105, U$118, U$123, U$136, U$141, U$154, U$159, U$172, U$177, U$190, U$195, U$208, U$213, U$226, U$231, U$244, U$249, U$262, U$267, U$280, U$285, U$298, U$303, U$316, U$321, U$334, U$339, U$352, U$357, U$370, U$375, U$388, U$393, U$406, U$411, U$424, U$429, U$442, U$447, U$460, U$465, U$478, U$483, U$496, U$501: SCL2
U$17, U$30, U$48, U$66, U$84, U$102, U$120, U$138, U$156, U$174, U$192, U$210, U$228, U$246, U$264, U$282, U$300, U$318, U$336, U$354, U$372, U$390, U$408, U$426, U$444, U$462, U$480, U$498: STAT0
U$18, U$31, U$49, U$67, U$85, U$103, U$121, U$139, U$157, U$175, U$193, U$211, U$229, U$247, U$265, U$283, U$301, U$319, U$337, U$355, U$373, U$391, U$409, U$427, U$445, U$463, U$481, U$499: OPENLOG0
U$20, U$35, U$53, U$71, U$89, U$107, U$125, U$143, U$161, U$179, U$197, U$215, U$233, U$251, U$269, U$287, U$305, U$323, U$341, U$359, U$377, U$395, U$413, U$431, U$449, U$467, U$485, U$503: GND1

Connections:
3.3V: C1.1, C3.2, I2C.2, J1.VCC, J2.2, J3.2, J4.2, J5.2, J6.3, R2.2, R3.2, U2.4, U2.6, U2.18, U2.20
3.3V1: C4.2, C6.1, I2C1.2, J7.2, J8.2, J9.2, J10.2, J11.3, J12.VCC, R7.2, R12.2, U1.4, U1.6, U1.18, U1.20
3.3V2: C7.2, C9.1, I2C2.2, J13.2, J14.2, J15.2, J16.2, J17.3, J18.VCC, R13.2, R18.2, U3.4, U3.6, U3.18, U3.20
3.3V3: C10.2, C12.1, I2C3.2, J19.2, J20.2, J21.2, J22.2, J23.3, J24.VCC, R19.2, R24.2, U4.4, U4.6, U4.18, U4.20
3.3V4: C13.2, C15.1, I2C4.2, J25.2, J26.2, J27.2, J28.2, J29.3, J30.VCC, R25.2, R30.2, U5.4, U5.6, U5.18, U5.20
3.3V5: C16.2, C18.1, I2C5.2, J31.2, J32.2, J33.2, J34.2, J35.3, J36.VCC, R31.2, R36.2, U6.4, U6.6, U6.18, U6.20
3.3V6: C19.2, C21.1, I2C6.2, J37.2, J38.2, J39.2, J40.2, J41.3, J42.VCC, R37.2, R42.2, U7.4, U7.6, U7.18, U7.20
3.3V7: C22.2, C24.1, I2C7.2, J43.2, J44.2, J45.2, J46.2, J47.3, J48.VCC, R43.2, R48.2, U8.4, U8.6, U8.18, U8.20
3.3V8: C25.2, C27.1, I2C8.2, J49.2, J50.2, J51.2, J52.2, J53.3, J54.VCC, R49.2, R54.2, U9.4, U9.6, U9.18, U9.20
3.3V9: C28.2, C30.1, I2C9.2, J55.2, J56.2, J57.2, J58.2, J59.3, J60.VCC, R55.2, R60.2, U10.4, U10.6, U10.18, U10.20
3.3V10: C31.2, C33.1, I2C10.2, J61.2, J62.2, J63.2, J64.2, J65.3, J66.VCC, R61.2, R66.2, U11.4, U11.6, U11.18, U11.20
3.3V11: C34.2, C36.1, I2C11.2, J67.2, J68.2, J69.2, J70.2, J71.3, J72.VCC, R67.2, R72.2, U12.4, U12.6, U12.18, U12.20
3.3V12: C37.2, C39.1, I2C12.2, J73.2, J74.2, J75.2, J76.2, J77.3, J78.VCC, R73.2, R78.2, U13.4, U13.6, U13.18, U13.20
3.3V13: C40.2, C42.1, I2C13.2, J79.2, J80.2, J81.2, J82.2, J83.3, J84.VCC, R79.2, R84.2, U14.4, U14.6, U14.18, U14.20
3.3V14: C43.2, C45.1, I2C14.2, J85.2, J86.2, J87.2, J88.2, J89.3, J90.VCC, R85.2, R90.2, U15.4, U15.6, U15.18, U15.20
3.3V15: C46.2, C48.1, I2C15.2, J91.2, J92.2, J93.2, J94.2, J95.3, J96.VCC, R91.2, R96.2, U16.4, U16.6, U16.18, U16.20
3.3V16: C49.2, C51.1, I2C16.2, J97.2, J98.2, J99.2, J100.2, J101.3, J102.VCC, R97.2, R102.2, U17.4, U17.6, U17.18, U17.20
3.3V17: C52.2, C54.1, I2C17.2, J103.2, J104.2, J105.2, J106.2, J107.3, J108.VCC, R103.2, R108.2, U18.4, U18.6, U18.18, U18.20
3.3V18: C55.2, C57.1, I2C18.2, J109.2, J110.2, J111.2, J112.2, J113.3, J114.VCC, R109.2, R114.2, U19.4, U19.6, U19.18, U19.20
3.3V19: C58.2, C60.1, I2C19.2, J115.2, J116.2, J117.2, J118.2, J119.3, J120.VCC, R115.2, R120.2, U20.4, U20.6, U20.18, U20.20
3.3V20: C61.2, C63.1, I2C20.2, J121.2, J122.2, J123.2, J124.2, J125.3, J126.VCC, R121.2, R126.2, U21.4, U21.6, U21.18, U21.20
3.3V21: C64.2, C66.1, I2C21.2, J127.2, J128.2, J129.2, J130.2, J131.3, J132.VCC, R127.2, R132.2, U22.4, U22.6, U22.18, U22.20
3.3V22: C67.2, C69.1, I2C22.2, J133.2, J134.2, J135.2, J136.2, J137.3, J138.VCC, R133.2, R138.2, U23.4, U23.6, U23.18, U23.20
3.3V23: C70.2, C72.1, I2C23.2, J139.2, J140.2, J141.2, J142.2, J143.3, J144.VCC, R139.2, R144.2, U24.4, U24.6, U24.18, U24.20
3.3V24: C73.2, C75.1, I2C24.2, J145.2, J146.2, J147.2, J148.2, J149.3, J150.VCC, R145.2, R150.2, U25.4, U25.6, U25.18, U25.20
3.3V25: C76.2, C78.1, I2C25.2, J151.2, J152.2, J153.2, J154.2, J155.3, J156.VCC, R151.2, R156.2, U26.4, U26.6, U26.18, U26.20
3.3V26: C79.2, C81.1, I2C26.2, J157.2, J158.2, J159.2, J160.2, J161.3, J162.VCC, R157.2, R162.2, U27.4, U27.6, U27.18, U27.20
3.3V27: C82.2, C84.1, I2C27.2, J163.2, J164.2, J165.2, J166.2, J167.3, J168.VCC, R163.2, R168.2, U28.4, U28.6, U28.18, U28.20
ADDR: ADR.2, U2.1
ADDR1: ADR1.2, U1.1
ADDR2: ADR2.2, U3.1
ADDR3: ADR3.2, U4.1
ADDR4: ADR4.2, U5.1
ADDR5: ADR5.2, U6.1
ADDR6: ADR6.2, U7.1
ADDR7: ADR7.2, U8.1
ADDR8: ADR8.2, U9.1
ADDR9: ADR9.2, U10.1
ADDR10: ADR10.2, U11.1
ADDR11: ADR11.2, U12.1
ADDR12: ADR12.2, U13.1
ADDR13: ADR13.2, U14.1
ADDR14: ADR14.2, U15.1
ADDR15: ADR15.2, U16.1
ADDR16: ADR16.2, U17.1
ADDR17: ADR17.2, U18.1
ADDR18: ADR18.2, U19.1
ADDR19: ADR19.2, U20.1
ADDR20: ADR20.2, U21.1
ADDR21: ADR21.2, U22.1
ADDR22: ADR22.2, U23.1
ADDR23: ADR23.2, U24.1
ADDR24: ADR24.2, U25.1
ADDR25: ADR25.2, U26.1
ADDR26: ADR26.2, U27.1
ADDR27: ADR27.2, U28.1
CS: J1.CS, R3.1, U2.14
CS1: J12.CS, R12.1, U1.14
CS2: J18.CS, R18.1, U3.14
CS3: J24.CS, R24.1, U4.14
CS4: J30.CS, R30.1, U5.14
CS5: J36.CS, R36.1, U6.14
CS6: J42.CS, R42.1, U7.14
CS7: J48.CS, R48.1, U8.14
CS8: J54.CS, R54.1, U9.14
CS9: J60.CS, R60.1, U10.14
CS10: J66.CS, R66.1, U11.14
CS11: J72.CS, R72.1, U12.14
CS12: J78.CS, R78.1, U13.14
CS13: J84.CS, R84.1, U14.14
CS14: J90.CS, R90.1, U15.14
CS15: J96.CS, R96.1, U16.14
CS16: J102.CS, R102.1, U17.14
CS17: J108.CS, R108.1, U18.14
CS18: J114.CS, R114.1, U19.14
CS19: J120.CS, R120.1, U20.14
CS20: J126.CS, R126.1, U21.14
CS21: J132.CS, R132.1, U22.14
CS22: J138.CS, R138.1, U23.14
CS23: J144.CS, R144.1, U24.14
CS24: J150.CS, R150.1, U25.14
CS25: J156.CS, R156.1, U26.14
CS26: J162.CS, R162.1, U27.14
CS27: J168.CS, R168.1, U28.14
DTR: C2.2, J6.6
DTR1: C5.2, J11.6
DTR2: C8.2, J17.6
DTR3: C11.2, J23.6
DTR4: C14.2, J29.6
DTR5: C17.2, J35.6
DTR6: C20.2, J41.6
DTR7: C23.2, J47.6
DTR8: C26.2, J53.6
DTR9: C29.2, J59.6
DTR10: C32.2, J65.6
DTR11: C35.2, J71.6
DTR12: C38.2, J77.6
DTR13: C41.2, J83.6
DTR14: C44.2, J89.6
DTR15: C47.2, J95.6
DTR16: C50.2, J101.6
DTR17: C53.2, J107.6
DTR18: C56.2, J113.6
DTR19: C59.2, J119.6
DTR20: C62.2, J125.6
DTR21: C65.2, J131.6
DTR22: C68.2, J137.6
DTR23: C71.2, J143.6
DTR24: C74.2, J149.6
DTR25: C77.2, J155.6
DTR26: C80.2, J161.6
DTR27: C83.2, J167.6
GND: ADR.1, C1.2, C3.1, D1.C, D3.C, J1.GND, J2.1, J3.1, J4.1, J5.6, J6.1, J6.2, Q1.2, U2.3, U2.5, U2.21
GND1: ADR1.1, C4.1, C6.2, D2.C, D4.C, J7.1, J8.1, J9.1, J10.6, J11.1, J11.2, J12.GND, Q2.2, U1.3, U1.5, U1.21
GND2: ADR2.1, C7.1, C9.2, D5.C, D6.C, J13.1, J14.1, J15.1, J16.6, J17.1, J17.2, J18.GND, Q3.2, U3.3, U3.5, U3.21
GND3: ADR3.1, C10.1, C12.2, D7.C, D8.C, J19.1, J20.1, J21.1, J22.6, J23.1, J23.2, J24.GND, Q4.2, U4.3, U4.5, U4.21
GND4: ADR4.1, C13.1, C15.2, D9.C, D10.C, J25.1, J26.1, J27.1, J28.6, J29.1, J29.2, J30.GND, Q5.2, U5.3, U5.5, U5.21
GND5: ADR5.1, C16.1, C18.2, D11.C, D12.C, J31.1, J32.1, J33.1, J34.6, J35.1, J35.2, J36.GND, Q6.2, U6.3, U6.5, U6.21
GND6: ADR6.1, C19.1, C21.2, D13.C, D14.C, J37.1, J38.1, J39.1, J40.6, J41.1, J41.2, J42.GND, Q7.2, U7.3, U7.5, U7.21
GND7: ADR7.1, C22.1, C24.2, D15.C, D16.C, J43.1, J44.1, J45.1, J46.6, J47.1, J47.2, J48.GND, Q8.2, U8.3, U8.5, U8.21
GND8: ADR8.1, C25.1, C27.2, D17.C, D18.C, J49.1, J50.1, J51.1, J52.6, J53.1, J53.2, J54.GND, Q9.2, U9.3, U9.5, U9.21
GND9: ADR9.1, C28.1, C30.2, D19.C, D20.C, J55.1, J56.1, J57.1, J58.6, J59.1, J59.2, J60.GND, Q10.2, U10.3, U10.5, U10.21
GND10: ADR10.1, C31.1, C33.2, D21.C, D22.C, J61.1, J62.1, J63.1, J64.6, J65.1, J65.2, J66.GND, Q11.2, U11.3, U11.5, U11.21
GND11: ADR11.1, C34.1, C36.2, D23.C, D24.C, J67.1, J68.1, J69.1, J70.6, J71.1, J71.2, J72.GND, Q12.2, U12.3, U12.5, U12.21
GND12: ADR12.1, C37.1, C39.2, D25.C, D26.C, J73.1, J74.1, J75.1, J76.6, J77.1, J77.2, J78.GND, Q13.2, U13.3, U13.5, U13.21
GND13: ADR13.1, C40.1, C42.2, D27.C, D28.C, J79.1, J80.1, J81.1, J82.6, J83.1, J83.2, J84.GND, Q14.2, U14.3, U14.5, U14.21
GND14: ADR14.1, C43.1, C45.2, D29.C, D30.C, J85.1, J86.1, J87.1, J88.6, J89.1, J89.2, J90.GND, Q15.2, U15.3, U15.5, U15.21
GND15: ADR15.1, C46.1, C48.2, D31.C, D32.C, J91.1, J92.1, J93.1, J94.6, J95.1, J95.2, J96.GND, Q16.2, U16.3, U16.5, U16.21
GND16: ADR16.1, C49.1, C51.2, D33.C, D34.C, J97.1, J98.1, J99.1, J100.6, J101.1, J101.2, J102.GND, Q17.2, U17.3, U17.5, U17.21
GND17: ADR17.1, C52.1, C54.2, D35.C, D36.C, J103.1, J104.1, J105.1, J106.6, J107.1, J107.2, J108.GND, Q18.2, U18.3, U18.5, U18.21
GND18: ADR18.1, C55.1, C57.2, D37.C, D38.C, J109.1, J110.1, J111.1, J112.6, J113.1, J113.2, J114.GND, Q19.2, U19.3, U19.5, U19.21
GND19: ADR19.1, C58.1, C60.2, D39.C, D40.C, J115.1, J116.1, J117.1, J118.6, J119.1, J119.2, J120.GND, Q20.2, U20.3, U20.5, U20.21
GND20: ADR20.1, C61.1, C63.2, D41.C, D42.C, J121.1, J122.1, J123.1, J124.6, J125.1, J125.2, J126.GND, Q21.2, U21.3, U21.5, U21.21
GND21: ADR21.1, C64.1, C66.2, D43.C, D44.C, J127.1, J128.1, J129.1, J130.6, J131.1, J131.2, J132.GND, Q22.2, U22.3, U22.5, U22.21
GND22: ADR22.1, C67.1, C69.2, D45.C, D46.C, J133.1, J134.1, J135.1, J136.6, J137.1, J137.2, J138.GND, Q23.2, U23.3, U23.5, U23.21
GND23: ADR23.1, C70.1, C72.2, D47.C, D48.C, J139.1, J140.1, J141.1, J142.6, J143.1, J143.2, J144.GND, Q24.2, U24.3, U24.5, U24.21
GND24: ADR24.1, C73.1, C75.2, D49.C, D50.C, J145.1, J146.1, J147.1, J148.6, J149.1, J149.2, J150.GND, Q25.2, U25.3, U25.5, U25.21
GND25: ADR25.1, C76.1, C78.2, D51.C, D52.C, J151.1, J152.1, J153.1, J154.6, J155.1, J155.2, J156.GND, Q26.2, U26.3, U26.5, U26.21
GND26: ADR26.1, C79.1, C81.2, D53.C, D54.C, J157.1, J158.1, J159.1, J160.6, J161.1, J161.2, J162.GND, Q27.2, U27.3, U27.5, U27.21
GND27: ADR27.1, C82.1, C84.2, D55.C, D56.C, J163.1, J164.1, J165.1, J166.6, J167.1, J167.2, J168.GND, Q28.2, U28.3, U28.5, U28.21
MISO: J1.DO, J5.1, U2.16
MISO1: J10.1, J12.DO, U1.16
MISO2: J16.1, J18.DO, U3.16
MISO3: J22.1, J24.DO, U4.16
MISO4: J28.1, J30.DO, U5.16
MISO5: J34.1, J36.DO, U6.16
MISO6: J40.1, J42.DO, U7.16
MISO7: J46.1, J48.DO, U8.16
MISO8: J52.1, J54.DO, U9.16
MISO9: J58.1, J60.DO, U10.16
MISO10: J64.1, J66.DO, U11.16
MISO11: J70.1, J72.DO, U12.16
MISO12: J76.1, J78.DO, U13.16
MISO13: J82.1, J84.DO, U14.16
MISO14: J88.1, J90.DO, U15.16
MISO15: J94.1, J96.DO, U16.16
MISO16: J100.1, J102.DO, U17.16
MISO17: J106.1, J108.DO, U18.16
MISO18: J112.1, J114.DO, U19.16
MISO19: J118.1, J120.DO, U20.16
MISO20: J124.1, J126.DO, U21.16
MISO21: J130.1, J132.DO, U22.16
MISO22: J136.1, J138.DO, U23.16
MISO23: J142.1, J144.DO, U24.16
MISO24: J148.1, J150.DO, U25.16
MISO25: J154.1, J156.DO, U26.16
MISO26: J160.1, J162.DO, U27.16
MISO27: J166.1, J168.DO, U28.16
MOSI: J1.DI, J5.4, U2.15
MOSI1: J10.4, J12.DI, U1.15
MOSI2: J16.4, J18.DI, U3.15
MOSI3: J22.4, J24.DI, U4.15
MOSI4: J28.4, J30.DI, U5.15
MOSI5: J34.4, J36.DI, U6.15
MOSI6: J40.4, J42.DI, U7.15
MOSI7: J46.4, J48.DI, U8.15
MOSI8: J52.4, J54.DI, U9.15
MOSI9: J58.4, J60.DI, U10.15
MOSI10: J64.4, J66.DI, U11.15
MOSI11: J70.4, J72.DI, U12.15
MOSI12: J76.4, J78.DI, U13.15
MOSI13: J82.4, J84.DI, U14.15
MOSI14: J88.4, J90.DI, U15.15
MOSI15: J94.4, J96.DI, U16.15
MOSI16: J100.4, J102.DI, U17.15
MOSI17: J106.4, J108.DI, U18.15
MOSI18: J112.4, J114.DI, U19.15
MOSI19: J118.4, J120.DI, U20.15
MOSI20: J124.4, J126.DI, U21.15
MOSI21: J130.4, J132.DI, U22.15
MOSI22: J136.4, J138.DI, U23.15
MOSI23: J142.4, J144.DI, U24.15
MOSI24: J148.4, J150.DI, U25.15
MOSI25: J154.4, J156.DI, U26.15
MOSI26: J160.4, J162.DI, U27.15
MOSI27: J166.4, J168.DI, U28.15
unnamed: Q1.1, U2.8
unnamed: Q1.3, U2.7
unnamed: D1.A, R1.2
unnamed: R1.1, U2.9
unnamed: I2C.1, R5.2
unnamed: I2C.3, R4.2
unnamed: D3.A, R6.2
unnamed: D2.A, R8.2
unnamed: Q2.1, U1.8
unnamed: Q2.3, U1.7
unnamed: D4.A, R9.2
unnamed: R9.1, U1.9
unnamed: I2C1.1, R11.2
unnamed: I2C1.3, R10.2
unnamed: D5.A, R14.2
unnamed: Q3.1, U3.8
unnamed: Q3.3, U3.7
unnamed: D6.A, R15.2
unnamed: R15.1, U3.9
unnamed: I2C2.1, R17.2
unnamed: I2C2.3, R16.2
unnamed: D7.A, R20.2
unnamed: Q4.1, U4.8
unnamed: Q4.3, U4.7
unnamed: D8.A, R21.2
unnamed: R21.1, U4.9
unnamed: I2C3.1, R23.2
unnamed: I2C3.3, R22.2
unnamed: D9.A, R26.2
unnamed: Q5.1, U5.8
unnamed: Q5.3, U5.7
unnamed: D10.A, R27.2
unnamed: R27.1, U5.9
unnamed: I2C4.1, R29.2
unnamed: I2C4.3, R28.2
unnamed: D11.A, R32.2
unnamed: Q6.1, U6.8
unnamed: Q6.3, U6.7
unnamed: D12.A, R33.2
unnamed: R33.1, U6.9
unnamed: I2C5.1, R35.2
unnamed: I2C5.3, R34.2
unnamed: D13.A, R38.2
unnamed: Q7.1, U7.8
unnamed: Q7.3, U7.7
unnamed: D14.A, R39.2
unnamed: R39.1, U7.9
unnamed: I2C6.1, R41.2
unnamed: I2C6.3, R40.2
unnamed: D15.A, R44.2
unnamed: Q8.1, U8.8
unnamed: Q8.3, U8.7
unnamed: D16.A, R45.2
unnamed: R45.1, U8.9
unnamed: I2C7.1, R47.2
unnamed: I2C7.3, R46.2
unnamed: D17.A, R50.2
unnamed: Q9.1, U9.8
unnamed: Q9.3, U9.7
unnamed: D18.A, R51.2
unnamed: R51.1, U9.9
unnamed: I2C8.1, R53.2
unnamed: I2C8.3, R52.2
unnamed: D19.A, R56.2
unnamed: Q10.1, U10.8
unnamed: Q10.3, U10.7
unnamed: D20.A, R57.2
unnamed: R57.1, U10.9
unnamed: I2C9.1, R59.2
unnamed: I2C9.3, R58.2
unnamed: D21.A, R62.2
unnamed: Q11.1, U11.8
unnamed: Q11.3, U11.7
unnamed: D22.A, R63.2
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

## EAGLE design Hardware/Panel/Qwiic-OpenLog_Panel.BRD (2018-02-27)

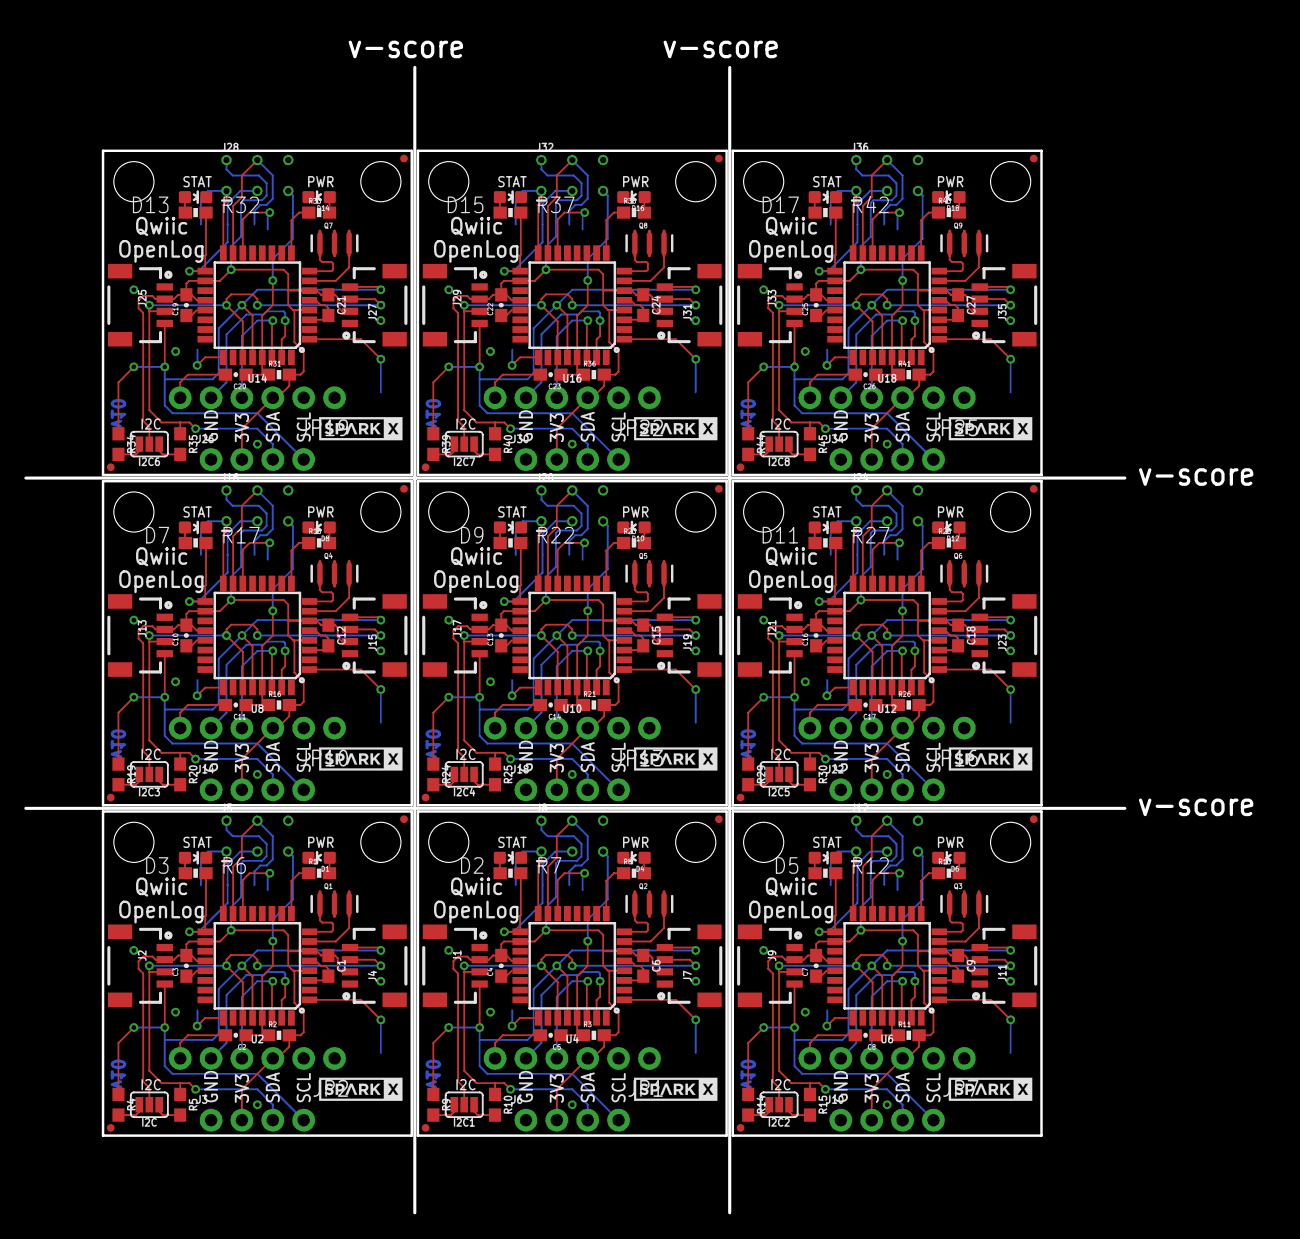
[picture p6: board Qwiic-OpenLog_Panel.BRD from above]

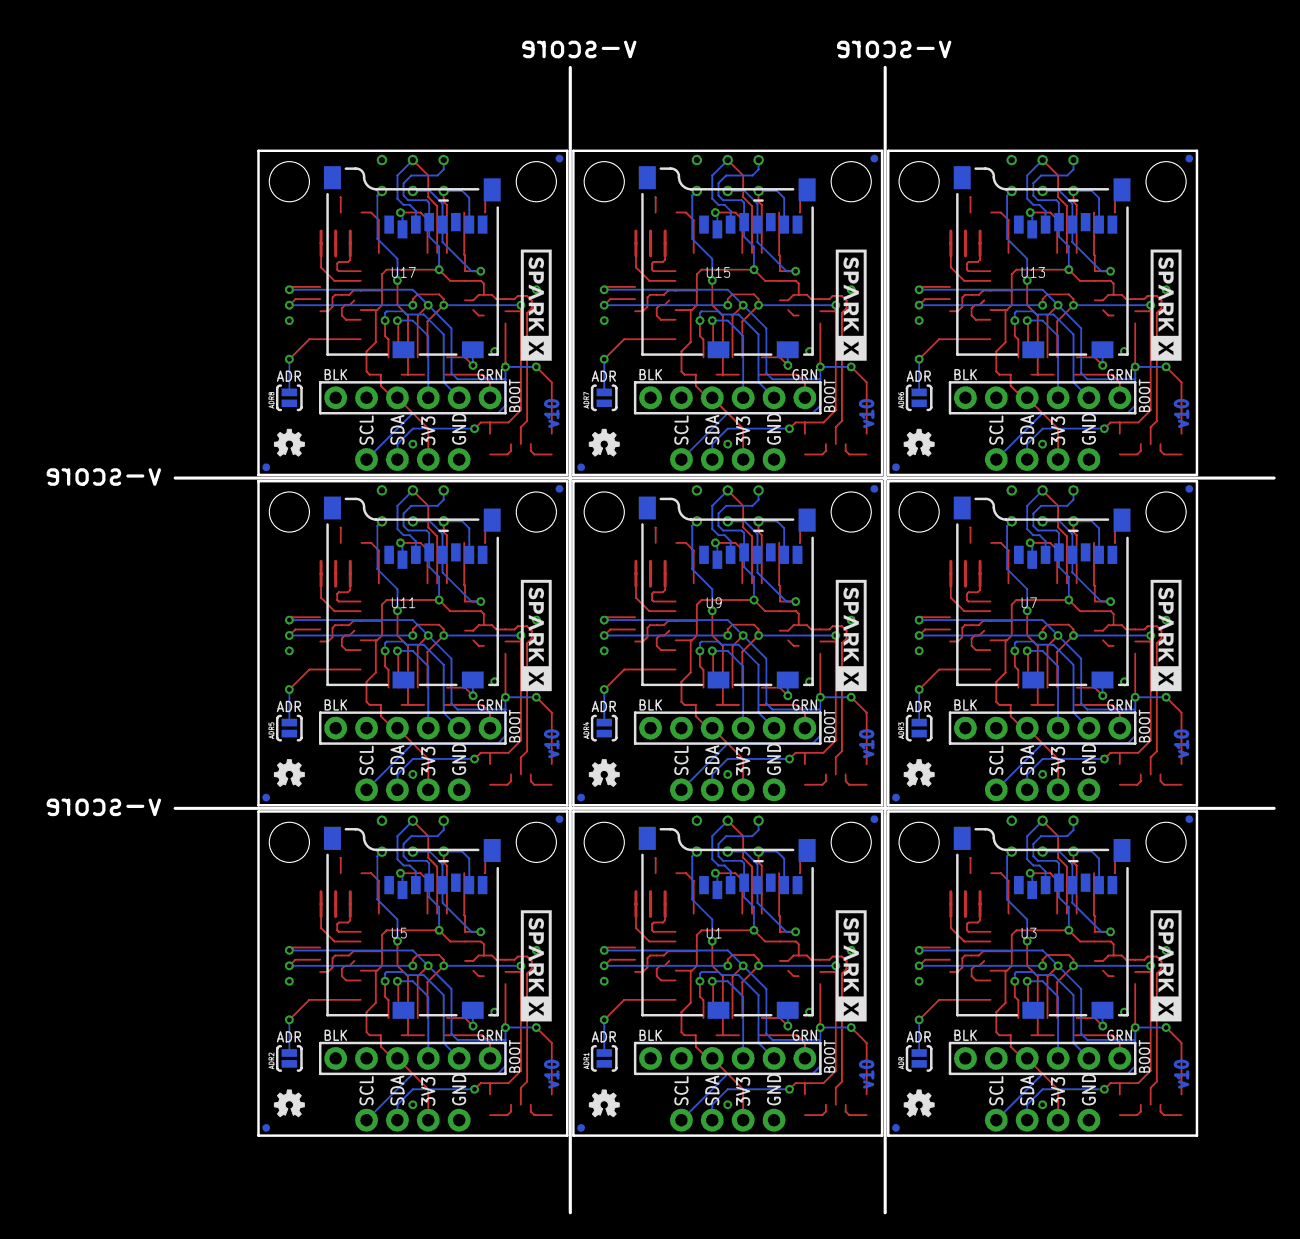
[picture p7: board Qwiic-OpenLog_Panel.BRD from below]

Board: 2 copper layers, 90.4 x 94.2 mm, 261 parts (54 on the bottom side), 189 nets.

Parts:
ADR, ADR1, ADR2, ADR3, ADR4, ADR5, ADR6, ADR7, ADR8: SJ_2S-NO
C1, C6, C9, C12, C15, C18, C21, C24, C27: 4.7uF; 0603
C2, C3, C4, C5, C7, C8, C10, C11, C13, C14, C16, C17, C19, C20, C22, C23, C25, C26: 0.1uF; 0603-CAP
D1, D4, D6, D8, D10, D12, D14, D16, D18: RED; LED-0603
D2, D3, D5, D7, D9, D11, D13, D15, D17: GREEN; LED-0603
FID1, FID2, FID3, FID4, FID5, FID6, FID7, FID8, FID9, FID10, FID11, FID12, FID13, FID14, FID15, FID16, FID17, FID18, FID19, FID20, FID21, FID22, FID23, FID24, FID25, FID26, FID27, FID28, FID29, FID30, FID31, FID32, FID33, FID34, FID35, FID36: FIDUCIALUFIDUCIAL; MICRO-FIDUCIAL
I2C, I2C1, I2C2, I2C3, I2C4, I2C5, I2C6, I2C7, I2C8: SMT-JUMPER_3_2-NC_PASTE_SILK
J1, J2, J4, J7, J9, J11, J13, J15, J17, J19, J21, J23, J25, J27, J29, J31, J33, J35: SMD; 1X04_1MM_RA
J3, J6, J10, J14, J18, J22, J26, J30, J34: PTH; 1X04_NO_SILK
J5, J8, J12, J16, J20, J24, J28, J32, J36: ISP; 2X3_TEST_POINTS
JP1, JP2, JP7, JP10, JP13, JP16, JP19, JP22, JP25: BOOT; 1X06_NO_SILK
JP3, JP4, JP5, JP6, JP8, JP9, JP11, JP12, JP14, JP15, JP17, JP18, JP20, JP21, JP23, JP24, JP26, JP27: STAND-OFF
LOGO1, LOGO2, LOGO3, LOGO4, LOGO5, LOGO6, LOGO7, LOGO8, LOGO9: OSHW-LOGOMINI; OSHW-LOGO-MINI
Q1, Q2, Q3, Q4, Q5, Q6, Q7, Q8, Q9: 16MHZ; RESONATOR-SMD
R1, R8, R13, R18, R23, R28, R33, R38, R43: 1K; 0603-RES
R2, R3, R11, R16, R21, R26, R31, R36, R41: 10K; 0603-RES
R4, R5, R9, R10, R14, R15, R19, R20, R24, R25, R29, R30, R34, R35, R39, R40, R44, R45: 2.2k; 0603
R6, R7, R12, R17, R22, R27, R32, R37, R42: 330; 0603-RES
U1, U3, U5, U7, U9, U11, U13, U15, U17: microSD Socket; MICRO-SD-SOCKET-PP
U2, U4, U6, U8, U10, U12, U14, U16, U18: ATMEGA328P_TQFP; TQFP32-08
U$1, U$4, U$6, U$8, U$10, U$12, U$14, U$16, U$18: SPARKX-LOGO4; SPARKX-MEDIUM
U$2, U$3, U$5, U$7, U$9, U$11, U$13, U$15, U$17: SPARKX-LOGO3; SPARKX-SMALL

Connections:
3.3V: C1.1, C3.2, I2C.2, J2.2, J3.2, J4.2, J5.2, JP2.3, R2.2, U2.4, U2.6, U2.18, U2.20, U3.VCC
3.3V1: C4.2, C6.1, I2C1.2, J1.2, J6.2, J7.2, J8.2, JP1.3, R3.2, U1.VCC, U4.4, U4.6, U4.18, U4.20
3.3V2: C7.2, C9.1, I2C2.2, J9.2, J10.2, J11.2, J12.2, JP7.3, R11.2, U5.VCC, U6.4, U6.6, U6.18, U6.20
3.3V3: C10.2, C12.1, I2C3.2, J13.2, J14.2, J15.2, J16.2, JP10.3, R16.2, U7.VCC, U8.4, U8.6, U8.18, U8.20
3.3V4: C13.2, C15.1, I2C4.2, J17.2, J18.2, J19.2, J20.2, JP13.3, R21.2, U9.VCC, U10.4, U10.6, U10.18, U10.20
3.3V5: C16.2, C18.1, I2C5.2, J21.2, J22.2, J23.2, J24.2, JP16.3, R26.2, U11.VCC, U12.4, U12.6, U12.18, U12.20
3.3V6: C19.2, C21.1, I2C6.2, J25.2, J26.2, J27.2, J28.2, JP19.3, R31.2, U13.VCC, U14.4, U14.6, U14.18, U14.20
3.3V7: C22.2, C24.1, I2C7.2, J29.2, J30.2, J31.2, J32.2, JP22.3, R36.2, U15.VCC, U16.4, U16.6, U16.18, U16.20
3.3V8: C25.2, C27.1, I2C8.2, J33.2, J34.2, J35.2, J36.2, JP25.3, R41.2, U17.VCC, U18.4, U18.6, U18.18, U18.20
ADDR: ADR.2, U2.1
ADDR1: ADR1.2, U4.1
ADDR2: ADR2.2, U6.1
ADDR3: ADR3.2, U8.1
ADDR4: ADR4.2, U10.1
ADDR5: ADR5.2, U12.1
ADDR6: ADR6.2, U14.1
ADDR7: ADR7.2, U16.1
ADDR8: ADR8.2, U18.1
CD: U2.25, U3.CD1
CD1: U1.CD1, U4.25
CD2: U5.CD1, U6.25
CD3: U7.CD1, U8.25
CD4: U9.CD1, U10.25
CD5: U11.CD1, U12.25
CD6: U13.CD1, U14.25
CD7: U15.CD1, U16.25
CD8: U17.CD1, U18.25
CS: U2.14, U3.CS
CS1: U1.CS, U4.14
CS2: U5.CS, U6.14
CS3: U7.CS, U8.14
CS4: U9.CS, U10.14
CS5: U11.CS, U12.14
CS6: U13.CS, U14.14
CS7: U15.CS, U16.14
CS8: U17.CS, U18.14
DTR: C2.2, JP2.6
DTR1: C5.2, JP1.6
DTR2: C8.2, JP7.6
DTR3: C11.2, JP10.6
DTR4: C14.2, JP13.6
DTR5: C17.2, JP16.6
DTR6: C20.2, JP19.6
DTR7: C23.2, JP22.6
DTR8: C26.2, JP25.6
GND: ADR.1, C1.2, C3.1, D1.C, D3.C, J2.1, J3.1, J4.1, J5.6, JP2.1, JP2.2, Q1.2, U2.3, U2.5, U2.21, U3.GND, U3.GND1, U3.GND3
GND1: ADR1.1, C4.1, C6.2, D2.C, D4.C, J1.1, J6.1, J7.1, J8.6, JP1.1, JP1.2, Q2.2, U1.GND, U1.GND1, U1.GND3, U4.3, U4.5, U4.21
GND2: ADR2.1, C7.1, C9.2, D5.C, D6.C, J9.1, J10.1, J11.1, J12.6, JP7.1, JP7.2, Q3.2, U5.GND, U5.GND1, U5.GND3, U6.3, U6.5, U6.21
GND3: ADR3.1, C10.1, C12.2, D7.C, D8.C, J13.1, J14.1, J15.1, J16.6, JP10.1, JP10.2, Q4.2, U7.GND, U7.GND1, U7.GND3, U8.3, U8.5, U8.21
GND4: ADR4.1, C13.1, C15.2, D9.C, D10.C, J17.1, J18.1, J19.1, J20.6, JP13.1, JP13.2, Q5.2, U9.GND, U9.GND1, U9.GND3, U10.3, U10.5, U10.21
GND5: ADR5.1, C16.1, C18.2, D11.C, D12.C, J21.1, J22.1, J23.1, J24.6, JP16.1, JP16.2, Q6.2, U11.GND, U11.GND1, U11.GND3, U12.3, U12.5, U12.21
GND6: ADR6.1, C19.1, C21.2, D13.C, D14.C, J25.1, J26.1, J27.1, J28.6, JP19.1, JP19.2, Q7.2, U13.GND, U13.GND1, U13.GND3, U14.3, U14.5, U14.21
GND7: ADR7.1, C22.1, C24.2, D15.C, D16.C, J29.1, J30.1, J31.1, J32.6, JP22.1, JP22.2, Q8.2, U15.GND, U15.GND1, U15.GND3, U16.3, U16.5, U16.21
GND8: ADR8.1, C25.1, C27.2, D17.C, D18.C, J33.1, J34.1, J35.1, J36.6, JP25.1, JP25.2, Q9.2, U17.GND, U17.GND1, U17.GND3, U18.3, U18.5, U18.21
MISO: J5.1, U2.16, U3.DO
MISO1: J8.1, U1.DO, U4.16
MISO2: J12.1, U5.DO, U6.16
MISO3: J16.1, U7.DO, U8.16
MISO4: J20.1, U9.DO, U10.16
MISO5: J24.1, U11.DO, U12.16
MISO6: J28.1, U13.DO, U14.16
MISO7: J32.1, U15.DO, U16.16
MISO8: J36.1, U17.DO, U18.16
MOSI: J5.4, U2.15, U3.DI
MOSI1: J8.4, U1.DI, U4.15
MOSI2: J12.4, U5.DI, U6.15
MOSI3: J16.4, U7.DI, U8.15
MOSI4: J20.4, U9.DI, U10.15
MOSI5: J24.4, U11.DI, U12.15
MOSI6: J28.4, U13.DI, U14.15
MOSI7: J32.4, U15.DI, U16.15
MOSI8: J36.4, U17.DI, U18.15
unnamed: Q1.1, U2.8
unnamed: Q1.3, U2.7
unnamed: D1.A, R1.2
unnamed: R1.1, U2.9
unnamed: I2C.1, R5.2
unnamed: I2C.3, R4.2
unnamed: D3.A, R6.2
unnamed: D2.A, R7.2
unnamed: Q2.1, U4.8
unnamed: Q2.3, U4.7
unnamed: D4.A, R8.2
unnamed: R8.1, U4.9
unnamed: I2C1.1, R10.2
unnamed: I2C1.3, R9.2
unnamed: D5.A, R12.2
unnamed: Q3.1, U6.8
unnamed: Q3.3, U6.7
unnamed: D6.A, R13.2
unnamed: R13.1, U6.9
unnamed: I2C2.1, R15.2
unnamed: I2C2.3, R14.2
unnamed: D7.A, R17.2
unnamed: Q4.1, U8.8
unnamed: Q4.3, U8.7
unnamed: D8.A, R18.2
unnamed: R18.1, U8.9
unnamed: I2C3.1, R20.2
unnamed: I2C3.3, R19.2
unnamed: D9.A, R22.2
unnamed: Q5.1, U10.8
unnamed: Q5.3, U10.7
unnamed: D10.A, R23.2
unnamed: R23.1, U10.9
unnamed: I2C4.1, R25.2
unnamed: I2C4.3, R24.2
unnamed: D11.A, R27.2
unnamed: Q6.1, U12.8
unnamed: Q6.3, U12.7
unnamed: D12.A, R28.2
unnamed: R28.1, U12.9
unnamed: I2C5.1, R30.2
unnamed: I2C5.3, R29.2
unnamed: D13.A, R32.2
unnamed: Q7.1, U14.8
unnamed: Q7.3, U14.7
unnamed: D14.A, R33.2
unnamed: R33.1, U14.9
unnamed: I2C6.1, R35.2
unnamed: I2C6.3, R34.2
unnamed: D15.A, R37.2
unnamed: Q8.1, U16.8
unnamed: Q8.3, U16.7
unnamed: D16.A, R38.2
unnamed: R38.1, U16.9
unnamed: I2C7.1, R40.2
unnamed: I2C7.3, R39.2
unnamed: D17.A, R42.2
unnamed: Q9.1, U18.8
unnamed: Q9.3, U18.7
unnamed: D18.A, R43.2
unnamed: R43.1, U18.9
unnamed: I2C8.1, R45.2
unnamed: I2C8.3, R44.2
RST: C2.1, J5.5, R2.1, U2.29
RST1: C5.1, J8.5, R3.1, U4.29
RST2: C8.1, J12.5, R11.1, U6.29
RST3: C11.1, J16.5, R16.1, U8.29
RST4: C14.1, J20.5, R21.1, U10.29
RST5: C17.1, J24.5, R26.1, U12.29
RST6: C20.1, J28.5, R31.1, U14.29
RST7: C23.1, J32.5, R36.1, U16.29
RST8: C26.1, J36.5, R41.1, U18.29
RXI: JP2.4, U2.30
RXI1: JP1.4, U4.30
RXI2: JP7.4, U6.30
RXI3: JP10.4, U8.30
RXI4: JP13.4, U10.30
RXI5: JP16.4, U12.30
RXI6: JP19.4, U14.30
RXI7: JP22.4, U16.30
RXI8: JP25.4, U18.30
SCK: J5.3, R6.1, U2.17, U3.SCLK
SCK1: J8.3, R7.1, U1.SCLK, U4.17
SCK2: J12.3, R12.1, U5.SCLK, U6.17
SCK3: J16.3, R17.1, U7.SCLK, U8.17
SCK4: J20.3, R22.1, U9.SCLK, U10.17
SCK5: J24.3, R27.1, U11.SCLK, U12.17
SCK6: J28.3, R32.1, U13.SCLK, U14.17
SCK7: J32.3, R37.1, U15.SCLK, U16.17
SCK8: J36.3, R42.1, U17.SCLK, U18.17
SCL: J2.4, J3.4, J4.4, R4.1, U2.28
SCL1: J1.4, J6.4, J7.4, R9.1, U4.28
SCL2: J9.4, J10.4, J11.4, R14.1, U6.28
SCL3: J13.4, J14.4, J15.4, R19.1, U8.28
SCL4: J17.4, J18.4, J19.4, R24.1, U10.28
SCL5: J21.4, J22.4, J23.4, R29.1, U12.28
SCL6: J25.4, J26.4, J27.4, R34.1, U14.28
SCL7: J29.4, J30.4, J31.4, R39.1, U16.28
SCL8: J33.4, J34.4, J35.4, R44.1, U18.28
SDA: J2.3, J3.3, J4.3, R5.1, U2.27
SDA1: J1.3, J6.3, J7.3, R10.1, U4.27
SDA2: J9.3, J10.3, J11.3, R15.1, U6.27
SDA3: J13.3, J14.3, J15.3, R20.1, U8.27
SDA4: J17.3, J18.3, J19.3, R25.1, U10.27
SDA5: J21.3, J22.3, J23.3, R30.1, U12.27
SDA6: J25.3, J26.3, J27.3, R35.1, U14.27
SDA7: J29.3, J30.3, J31.3, R40.1, U16.27
SDA8: J33.3, J34.3, J35.3, R45.1, U18.27
TXO: JP2.5, U2.31
TXO1: JP1.5, U4.31
TXO2: JP7.5, U6.31
TXO3: JP10.5, U8.31
TXO4: JP13.5, U10.31
TXO5: JP16.5, U12.31
TXO6: JP19.5, U14.31
TXO7: JP22.5, U16.31
TXO8: JP25.5, U18.31

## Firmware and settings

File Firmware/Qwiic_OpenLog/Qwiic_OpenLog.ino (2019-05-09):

/*
  An I2C based datalogger - Like the OpenLog but for I2C
  By: Nathan Seidle
  SparkFun Electronics
  Date: January 21st, 2018
  License: This code is public domain but you buy me a beer if you use this and we meet someday (Beerware license).

  Feel like supporting our work? Buy a board from SparkFun!
  https://www.sparkfun.com/products/14641

  Qwiic OpenLog records any incoming byte to the default log file. If quered by the master OpenLog will
  normally respond with a status byte with the following structure:

  Bit 0: SD/Init Good
  Bit 1: Last Command Succeeded
  Bit 2: Last Command Known
  Bit 3: File Currently Open
  Bit 4: In Root Directory
  Bit 5: 0 - Future Use
  Bit 6: 0 - Future Use
  Bit 7: 0 - Future Use

  At 115200bps with OpenLog Serial, it logged 11,520 bytes per second with a few buffer overruns
  At 100kHz I2C that's 10,000 bytes per second (10-bits per byte in I2C). Should be ok.
  At 400kHz, that's 40,000 bytes per second. We're going to need clock stretching.

  Red LED is 1.8V forward voltage. 3.3V - 1.8V = 1.5V across 1k = 1.5mA for the "PWR" LED

  3.5mA during idle
  12mA during constant write
  2.85mA idle, no card

  Why do we use NewSerial? NewSerial uses approximately 60 bytes less RAM than built-in Serial.

  Recording works great at 400kHz. Clock stretches correctly.
  The clock stretch occurs every 36ms, curious... Probably happening every 512 byte write

  Commands look like this:
  "new test.txt" - Create file 'test.txt' in current directory
  "append test.txt" - Create (if not exist) and append to file 'test.txt'
  "md day2" - Make directory day2
  "cd day2" - Change directory to day2
  "set 1" - Set recording type to SeqLog. 0 = Create new log each power up, 1 = Append to SeqLog
  "adr 98" - Change I2C address to 98. Valid/allowed addresses are 0x08 to 0x77.
  "esc 36" - Change escape character tp $. Valid 0 to 255
  "num 5" - Change number of escape characters to 5. Valid 0 to 255
  "log 100" - Change number of log to start at LOG00100.TXT. Valid 0 to 65,534
  If the master issues a read after these commands are sent, QOL responds with valueMap.status byte

  "ls" - List files and subdirectories in current directory
  "ls *.*" - List files in current directory
  "ls *<forwardslash>" - List subdirectories in current directory
  If the master issues a read after this command, QOL responds with /0 terminated string of object.
  Each subsequent read gets another object.
  Directory names end in / character.

  "rm LOG*.TXT" - Remove all files that have the name LOG?????.TXT.
  "rm MONDAY" - Remove the *empty* directory MONDAY
  "rm -rf MONDAY" - Remove the directory MONDAY and any files within it

  "size <file>" - Get size of file. -1 if file does not exist
  If the master issues a read after this command, QOL responds with 4 bytes, signed long of file size

  "read test.txt <start> <length> <type>" - Get contents of file
  If the master issues a read after this command, QOL responds with up to 32 bytes of file contents
  Used size command prior to read to determine the number of bytes to read.

  "get <setting>" - Get the value of a setting
  If the master issues a read after this command, QOL responds with the adr, esc, num, or set value

  "default" - Reset to all factory settings
  Normal logging, address to 42, escape to 26, escape num to 3, log number to zero.
  Begin logging with the first log number available

  (future) Set time/date via timestamp and dateTimeCallback() function

  TODO:
  Library
  See if increasing the buffer size(S) increases record from 21k to more
  Write example that scans for I2C devices to find lost OpenLog
  get file count command - number of files in this directory
  get directory count command - number of directories in this directory
  add command to force sync. Sometimes card is pulled before 500ms?
  When SD card is out, does OpenLog hang the I2C bus?
*/

#include <Wire.h>

#define __PROG_TYPES_COMPAT__ //Needed to get SerialPort.h to work in Arduino 1.6.x

#include <SPI.h>
#include <SdFat.h> //We do not use the built-in SD.h file because it calls Serial.print
#include "SerialPort.h" //This is a new/beta library written by Bill Greiman. You rock Bill!
#include <EEPROM.h>
#include <FreeStack.h> //Allows us to print the available stack/RAM size

SerialPort<0, 32, 32> NewSerial;
//This is a very important buffer declaration. This sets the <port #, rx size, tx size>. We set
//the TX buffer to zero because we will be spending most of our time needing to buffer the incoming (RX) characters.

#include <avr/sleep.h> //Needed for sleep_mode
#include <avr/power.h> //Needed for powering down perihperals such as the ADC/TWI and Timers

#define SD_CHIP_SELECT 10 //On OpenLog this is pin 10

//Debug turns on (1) or off (0) a bunch of verbose debug statements. Normally use (0)
//#define DEBUG  1
#define DEBUG  0

#define I2C_BUFFER_SIZE 32 //For ATmega328 based Arduinos, the I2C buffer is limited to 32 bytes

void(* Reset_AVR) (void) = 0; //Way of resetting the ATmega

//The bigger the receive buffer, the less likely we are to drop characters at high speed. However, the ATmega has a limited amount of
//RAM. This debug mode allows us to view available RAM at various stages of the program
#define RAM_TESTING  0 //Off
//#define RAM_TESTING  1 //On

//STAT1 is labeled PWR on QOL
#define STAT1  5 //On PORTD
#define STAT1_PORT  PORTD

//STAT2 is labeled STAT on QOL and sits on the SCK line of the SD interface
//LED illuminates when the SD card is actively writing/reading
#define STAT2  5 //On PORTB
#define STAT2_PORT  PORTB

const byte stat1 = 5;  //Used as a power indicator
const byte stat2 = 13; //This is the SPI LED, indicating SD traffic

//The I2C ADR jumper is on pin 3. Used to change the I2C address by decreasing it by 1.
//Default I2C address is 0x2A. When jumper is closed address goes down by one to 0x29.
const byte addr = 3;

//Blinking LED error codes
#define ERROR_SD_INIT   3
#define ERROR_CARD_INIT   6
#define ERROR_VOLUME_INIT 7
#define ERROR_ROOT_INIT   8
#define ERROR_FILE_OPEN   9

#define OFF   0x00
#define ON    0x01

#define LOCATION_SYSTEM_SETTING   0x02
#define LOCATION_FILE_NUMBER_LSB  0x03
#define LOCATION_FILE_NUMBER_MSB  0x04
#define LOCATION_ESCAPE_CHAR    0x05
#define LOCATION_MAX_ESCAPE_CHAR  0x06
#define LOCATION_I2C_ADDRESS    0x0D

SdFat sd;
SdFile workingFile; //This is the main file we are writing to or reading from

byte currentRegisterNumber;

const unsigned int MAX_IDLE_TIME_MSEC = 500; //Max idle time before unit syncs buffer and goes to sleep

//Variables used in the I2C interrupt
volatile byte setting_system_mode; //This is the mode the system runs in, default is MODE_NEWLOG
volatile byte setting_escape_character; //This is the ASCII character we look for to break logging, default is ctrl+z
volatile byte setting_max_escape_character; //Number of escape chars before break logging, default is 3

#define LOCAL_BUFFER_SIZE 256
byte incomingData[LOCAL_BUFFER_SIZE + 1]; //Local buffer to record I2C bytes before committing to file, add 1 for 0 character on end
volatile int incomingDataSpot = 0; //Keeps track of where we are in the incoming buffer
volatile unsigned long lastSyncTime = 0; //Keeps track of the last time the file was synced

//These are the different types of datums the OpenLog can respond with
enum Response {
  RESPONSE_STATUS, //1 byte containing status bits
  RESPONSE_VALUE, //File size, number of files removed, etc. May be 1, 2, or 4 bytes depending on what loads it
  RESPONSE_FILE_READ, //Up to 32 bytes of a given file's contents
  RESPONSE_FILE_LIST //Up to 32 ASCII characters for a file or directory name
};
volatile Response responseType = RESPONSE_STATUS; //State engine that let's us know what the master is asking for
byte responseBuffer[I2C_BUFFER_SIZE]; //Used to pass data back to master
volatile byte responseSize = 1; //Defines how many bytes of relevant data is contained in the responseBuffer

#define STATUS_SD_INIT_GOOD 0
#define STATUS_LAST_COMMAND_SUCCESS 1
#define STATUS_LAST_COMMAND_KNOWN 2
#define STATUS_FILE_OPEN 3
#define STATUS_IN_ROOT_DIRECTORY 4

char* fileListArguments; //When reading a list of files, we have to remember what to search for between I2C interrupts

volatile boolean newConfigData = false;

struct memoryMap {
  byte id;
  byte status;
  byte firmwareMajor;
  byte firmwareMinor;
  byte i2cAddress;
  byte logInit;
  byte createFile;
  byte mkDir;
  byte cd;
  byte readFile;
  byte startPosition;
  byte openFile;
  byte writeFile;
  byte fileSize;
  byte list;
  byte rm;
  byte rmrf;
  byte syncFile;
};

const memoryMap registerMap = {
  .id = 0x00,
  .status = 0x01,
  .firmwareMajor = 0x02,
  .firmwareMinor = 0x03,
  .i2cAddress = 0x1E,
  .logInit = 0x05,
  .createFile = 0x06,
  .mkDir = 0x07,
  .cd = 0x08,
  .readFile = 0x09,
  .startPosition = 0x0A,
  .openFile = 0x0B,
  .writeFile = 0x0C,
  .fileSize = 0x0D,
  .list = 0x0E,
  .rm = 0x0F,
  .rmrf = 0x10,
  .syncFile = 0x11,
};

volatile memoryMap valueMap = {
  .id = 0x78,
  .status = 0x00,
  .firmwareMajor = 0x03,
  .firmwareMinor = 0x01,
  .i2cAddress = 0x2A,
  .logInit = 0x00,
  .createFile = 0x00,
  .mkDir = 0x00,
  .cd = 0x00,
  .readFile = 0x00,
  .startPosition = 0x00,
  .openFile = 0x00,
  .writeFile = 0x00,
  .fileSize = 0x00,
  .list = 0x00,
  .rm = 0x00,
  .rmrf = 0x00,
  .syncFile = 0x00,
};

void idReturn(char *myData);
void statusReturn(char *myData);
void firmwareMajorReturn(char *myData);
void firmwareMinorReturn(char *myData);
void addressReturn(char *myData);
void initFunction(char *myData);
void createFile(char *myData);
void mkDir(char *myData);
void chDir(char *myData);
void readFile(char *myData);
void setStartPosition(char *myData);
void openFile(char *myData);
void writeFile(char *myData);
void fileSize(char *myData);
void listFiles(char *myData);
void removeFiles(char *myData);
void recursiveRemove(char *myData);
void syncFile(char *myData);

struct functionMap {
  byte registerNumber;
  void (*handleFunction)(char *myData);
};

functionMap functions[] = {
  {registerMap.id, idReturn},
  {registerMap.status, statusReturn},
  {registerMap.firmwareMajor, firmwareMajorReturn},
  {registerMap.firmwareMinor, firmwareMinorReturn},
  {registerMap.i2cAddress, addressReturn},
  {registerMap.logInit, initFunction},
  {registerMap.createFile, createFile},
  {registerMap.mkDir, mkDir},
  {registerMap.cd, chDir},
  {registerMap.readFile, readFile},
  {registerMap.startPosition, setStartPosition},
  {registerMap.openFile, openFile},
  {registerMap.writeFile, writeFile},
  {registerMap.fileSize, fileSize},
  {registerMap.list, listFiles},
  {registerMap.rm, removeFiles},
  {registerMap.rmrf, recursiveRemove},
  {registerMap.syncFile, syncFile},
};

void setup(void)
{
  pinMode(stat1, OUTPUT);
  pinMode(addr, INPUT_PULLUP);

  //Power down various bits of hardware to lower power usage
  set_sleep_mode(SLEEP_MODE_IDLE);
  sleep_enable();

  //Shut off Timer2, Timer1, ADC
  ADCSRA &= ~(1 << ADEN); //Disable ADC
  ACSR = (1 << ACD); //Disable the analog comparator
  DIDR0 = 0x3F; //Disable digital input buffers on all ADC0-ADC5 pins
  DIDR1 = (1 << AIN1D) | (1 << AIN0D); //Disable digital input buffer on AIN1/0

  power_timer1_disable();
  power_timer2_disable();
  power_adc_disable();

  readSystemSettings(); //Load all system settings from EEPROM

  //Begin listening on I2C only after we've setup all our config and opened any files
  Wire.onReceive(receiveEvent);
  Wire.onRequest(requestEvent);
  startI2C(); //Determine the I2C address we should be using and begin listening on I2C bus

  //Setup UART
  NewSerial.begin(9600);
  NewSerial.print(F("1"));

  //Setup SD & FAT
  if (sd.begin(SD_CHIP_SELECT, SPI_FULL_SPEED) == false)
  {
    valueMap.status &= ~(1 << STATUS_SD_INIT_GOOD); //Init failed
    systemError(ERROR_CARD_INIT);
  }
  valueMap.status |= (1 << STATUS_SD_INIT_GOOD); //Init success!

  if (sd.chdir() == false) //Change to root directory. All new file creation will be in root.
  {
    valueMap.status &= ~(1 << STATUS_SD_INIT_GOOD); //Init failed
    valueMap.status &= ~(1 << STATUS_IN_ROOT_DIRECTORY); //Init failed
    systemError(ERROR_ROOT_INIT);
  }
  valueMap.status |= (1 << STATUS_IN_ROOT_DIRECTORY); //We are in root

  NewSerial.print(F("2"));

  //Search for a config file and load any settings found. This will over-ride previous EEPROM settings if found.
  readConfigFile();

  //Our I2C address may have changed from the config file
  startI2C(); //Determine the I2C address we should be using and begin listening on I2C bus

  NewSerial.print(F("(Adr: 0x"));
  if (digitalRead(addr) == LOW)
    NewSerial.print(0x29, HEX);
  else
    NewSerial.print(valueMap.i2cAddress, HEX);
  NewSerial.print(F(")"));

#if DEBUG
  NewSerial.print(F("FreeStack: "));
  NewSerial.println(FreeStack());
#endif

  NewSerial.print(F("<")); //Prompt to indicate we are good to go

  digitalWrite(stat1, HIGH); //Turn on LED to indicate power/ok

  sd.chdir("/"); //Change 'volume working directory' to root

  valueMap.status |= (1 << STATUS_LAST_COMMAND_SUCCESS); //Last command was success (start up default)
  valueMap.status |= (1 << STATUS_LAST_COMMAND_KNOWN); //Last command was known (start up default)
}

void loop(void)
{
  //The I2C receiveEvent() interrupt records all incoming bytes to workingFile

  //If an amount of time passes, put OpenLog into low power mode
  if ( (millis() - lastSyncTime) > MAX_IDLE_TIME_MSEC) { //If we haven't received any characters after amount of time, goto sleep

    //STAT1_PORT &= ~(1 << STAT1); //Turn off stat LED to save power
    power_timer0_disable(); //Shut down peripherals we don't need
    power_spi_disable();
    power_usart0_disable();
    sleep_mode(); //Stop everything and go to sleep. Wake up if I2C event occurs.

    power_spi_enable(); //After wake up, power up peripherals
    power_timer0_enable();
    power_usart0_enable();

    lastSyncTime = millis(); //Reset the last sync time to now
  }

  //Check to see if we need to commit the current EEPROM settings to a file
  //OpenLog likes to crash if we try to do this in the command shell (which is inside the interrupt)
  if (newConfigData == true)
  {
    recordConfigFile(); //Put this new setting into the config file
    newConfigData = false;
  }
}

//When OpenLog receives data bytes, this function is called as an interrupt
//Arduino [Uno] buffer is limited to 32 bytes so we pull data into a second local buffer that is larger
//We also scan for control characters. If we detect enough of them, we have received a command.
//If a command is detected the command shell is run. This allows for clock stretching while we do file manipulations.
void receiveEvent(int numberOfBytesReceived)
{
  //I didn't see anywhere else in the code where lastSyncTime is actually updated so wouldn't it always go to
  //sleep after the same amount of time???
  lastSyncTime = millis();
  incomingDataSpot = 0;
  
  //because I'm paranoid
  memset(incomingData, 0, sizeof(incomingData));
  while (Wire.available())
  {
    currentRegisterNumber = Wire.read();
    while (Wire.available())
    {
      incomingData[incomingDataSpot++] = Wire.read();
      //incomingData is 32 bytes. We shouldn't spill over because receiveEvent can't receive more than 32 bytes
    }
  }
  for (int regNum = 0; regNum < (sizeof(memoryMap) / sizeof(byte)); regNum++)
  {
    if (functions[regNum].registerNumber == currentRegisterNumber)
    {
      valueMap.status &= ~(1 << STATUS_LAST_COMMAND_SUCCESS); //Assume command failed
      valueMap.status |= (1 << STATUS_LAST_COMMAND_KNOWN); //Assume command is known
      functions[regNum].handleFunction(incomingData);
    }
  }
  //Record bytes to local array
}

//Send back a number of bytes via an array, max 32 bytes
//When OpenLog gets a request for data from the user, this function is called as an interrupt
//The interrupt will respond with different types of data depending on what response state we are in
//The user sets the response type using the command interface
void requestEvent()
{
  lastSyncTime = millis();
  switch (responseType)
  {
    case RESPONSE_STATUS:
      //Respond with the system status byte
      Wire.write(valueMap.status);

      //Once read, clear the last command known and last command success bits
      valueMap.status &= ~(1 << STATUS_LAST_COMMAND_SUCCESS);
      valueMap.status &= ~(1 << STATUS_LAST_COMMAND_KNOWN);
      break;

    case RESPONSE_VALUE:
      //File size, number of files removed, etc. May be 1, 2, or 4 bytes depending on what loads it
      Wire.write(responseBuffer, responseSize);

      responseType = RESPONSE_STATUS; //Return to default state
      break;

    case RESPONSE_FILE_READ:
      //Respond with array containing up to 32 bytes of file contents
      Wire.write(responseBuffer, responseSize);

      //Fill the array with more bytes for the next call
      loadArrayWithFile();
      break;

    case RESPONSE_FILE_LIST:
      //Respond with a string of characters indicating the next file or directory name
      Wire.write(responseBuffer, responseSize);

      //Fill the array with more bytes for the next call
      loadArrayWithFileName(sd.vwd(), fileListArguments);
      break;

    default:
      Wire.write(0x80); //Unknown response state
      break;
  }
}


//Handle errors by printing the error type and blinking LEDs in certain way
//The function will never exit - it loops forever inside blink_error
void systemError(byte error_type)
{
  NewSerial.print(F("Error "));
  switch (error_type)
  {
    case ERROR_CARD_INIT:
      NewSerial.print(F("card.init"));
      blink_error(ERROR_SD_INIT);
      break;
    case ERROR_VOLUME_INIT:
      NewSerial.print(F("volume.init"));
      blink_error(ERROR_SD_INIT);
      break;
    case ERROR_ROOT_INIT:
      NewSerial.print(F("root.init"));
      blink_error(ERROR_SD_INIT);
      break;
    case ERROR_FILE_OPEN:
      NewSerial.print(F("file.open"));
      blink_error(ERROR_SD_INIT);
      break;
  }
}

//Blink the status LED to indicate an error
void blink_error(byte ERROR_TYPE)
{
  while (1)
  {
    for (byte x = 0 ; x < ERROR_TYPE ; x++)
    {
      digitalWrite(stat1, HIGH);
      delay(200);
      digitalWrite(stat1, LOW);
      delay(200);
    }

    delay(2000);
  }
}

//Begin listening on I2C bus as I2C slave using the global variable valueMap.i2cAddress
void startI2C()
{
  Wire.end();
  if (digitalRead(addr) == LOW)
    Wire.begin(0x29); //Force address to 0x29 if user has soldered jumper closed
  else
    Wire.begin(EEPROM.read(LOCATION_I2C_ADDRESS)); //Start I2C and answer calls using address from EEPROM
}

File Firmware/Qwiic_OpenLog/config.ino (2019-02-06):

/*
  These functions read and write to the config.txt file. They also set the global configuration variables.
*/

#define CFG_FILENAME "config.txt" //This is the name of the file that contains the unit settings

#define MAX_CFG "119,103,14,0" //Address 119, escape char of ASCII(103), 14 times, new log mode
#define CFG_LENGTH (strlen(MAX_CFG) + 1) //Length of text found in config file. strlen ignores \0 so we have to add it back 
#define SEQ_FILENAME "SEQLOG00.TXT" //This is the name for the file when you're in sequential modeu

//Internal EEPROM locations for the user settings
#define LOCATION_SYSTEM_SETTING   0x02
#define LOCATION_FILE_NUMBER_LSB  0x03
#define LOCATION_FILE_NUMBER_MSB  0x04
#define LOCATION_ESCAPE_CHAR    0x05
#define LOCATION_MAX_ESCAPE_CHAR  0x06
#define LOCATION_I2C_ADDRESS    0x0D

#define MODE_NEWLOG     0
#define MODE_SEQLOG     1

//Resets all the system settings to safe values
void setDefaultSettings(void)
{
  //Reset system to new log mode
  EEPROM.write(LOCATION_SYSTEM_SETTING, MODE_NEWLOG);

  //Reset escape character to ctrl+z
  EEPROM.write(LOCATION_ESCAPE_CHAR, 26);

  //Reset number of escape characters to 3
  EEPROM.write(LOCATION_MAX_ESCAPE_CHAR, 3);

  //Reset the I2C Address to default of 42
  EEPROM.write(LOCATION_I2C_ADDRESS, 42);

  //These settings are not recorded to the config file
  //We can't do it here because we are not sure the FAT system is init'd
}

//Reads the current system settings from EEPROM
//If anything looks weird, reset setting to default value
void readSystemSettings(void)
{
  //Determine the system mode we should be in
  //Default is NEWLOG mode
  setting_system_mode = EEPROM.read(LOCATION_SYSTEM_SETTING);
  if (setting_system_mode > 5)
  {
    setting_system_mode = MODE_NEWLOG; //By default, unit will turn on and go to new file logging
    EEPROM.write(LOCATION_SYSTEM_SETTING, setting_system_mode);
  }

  //Read the escape_character
  //Default is ASCII(26)/ctrl+z
  setting_escape_character = EEPROM.read(LOCATION_ESCAPE_CHAR);
  if (setting_escape_character == 0 || setting_escape_character == 255)
  {
    setting_escape_character = 26; //Reset escape character to ctrl+z
    EEPROM.write(LOCATION_ESCAPE_CHAR, setting_escape_character);
  }

  //Read the number of escape_characters to look for
  //Default is 3
  setting_max_escape_character = EEPROM.read(LOCATION_MAX_ESCAPE_CHAR);
  if (setting_max_escape_character == 255)
  {
    setting_max_escape_character = 3; //Reset number of escape characters to 3
    EEPROM.write(LOCATION_MAX_ESCAPE_CHAR, setting_max_escape_character);
  }

  //Read what I2C address we should use
  //Default is 42 (or 41 if jumper is closed)
  valueMap.i2cAddress = EEPROM.read(LOCATION_I2C_ADDRESS);
  if (valueMap.i2cAddress == 255)
  {
    valueMap.i2cAddress = 42; //By default, we listen for 42
    EEPROM.write(LOCATION_I2C_ADDRESS, valueMap.i2cAddress);
  }
}

void readConfigFile(void)
{
  SdFile configFile;

  if (!sd.chdir()) systemError(ERROR_ROOT_INIT); // open the root directory

  char configFileName[strlen(CFG_FILENAME)]; //Limited to 8.3
  strcpy_P(configFileName, PSTR(CFG_FILENAME)); //This is the name of the config file. 'config.sys' is probably a bad idea.

  //Check to see if we have a config file
  if (!configFile.open(configFileName, O_READ)) {
    //If we don't have a config file already, then create config file and record the current system settings to the file
#if DEBUG
    NewSerial.println(F("No config found - creating default:"));
#endif
    configFile.close();

    //Record the current eeprom settings to the config file
    recordConfigFile();
    return;
  }

  //If we found the config file then load settings from file and push them into EEPROM
#if DEBUG
  NewSerial.println(F("Found config file!"));
#endif

  //Read up to 13 characters from the file. There may be a better way of doing this...
  char c;
  byte settingsLength;

  byte settings_string[CFG_LENGTH]; //"119,103,14,0\n" = Address 119, escape char of ASCII(103), 14 times, new log mode

  for (settingsLength = 0 ; settingsLength < CFG_LENGTH ; settingsLength++) {
    if ( (c = configFile.read()) < 0) break; //We've reached the end of the file
    if (c == '\n') break; //Bail if we hit the end of this string
    settings_string[settingsLength] = c;
  }
  configFile.close();
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

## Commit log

2018-02-28 More examples. Finishing up v1.0.
    [OpenLog.csv, OpenLog.sch]
2018-03-01 Readme photo update. Adding production programming tools.
    [Qwiic-OpenLog.brd, Qwiic-OpenLog.sch]
2018-07-18 Updating with Buzzard labels
    [Qwiic-OpenLog-Panel.GBL, Qwiic-OpenLog-Panel.GBO, Qwiic-OpenLog-Panel.GBP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]
2019-02-05 Adding pull up on CS pin to allow for easier ISP programming.
    [Qwiic-OpenLog.brd, Qwiic-OpenLog.sch]
2019-02-05 Add v12 production panel
    [Qwiic-OpenLog-Panel.GBL, Qwiic-OpenLog-Panel.GBO, Qwiic-OpenLog-Panel.GBP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]
2019-05-02 ~160x faster write speed, ~2x effective storage size, may break compatibility with older code
    Changed writeFile so it:
    -doesn't sync to SD card every byte written
    -doesn't write an extra null character after every byte specified by the user to be written. sizeof(*myData) does *not* return the length of the string. It returns the size of the type pointer to char, which on the m328p is two bytes. Thus, every time writeFile is called it writes the byte the user supplied and the zeroed out byte right ahead of it. When you take out the sd card and view it on your computer you may not see this because a lot of text editors silently ignore most special ASCII characters. View in VIM or Sublime to se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
    [Qwiic_OpenLog.ino, commands.ino]

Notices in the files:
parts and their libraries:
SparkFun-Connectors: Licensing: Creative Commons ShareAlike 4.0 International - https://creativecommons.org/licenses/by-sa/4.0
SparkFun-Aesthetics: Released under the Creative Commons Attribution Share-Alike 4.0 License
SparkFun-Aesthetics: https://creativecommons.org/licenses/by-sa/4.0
